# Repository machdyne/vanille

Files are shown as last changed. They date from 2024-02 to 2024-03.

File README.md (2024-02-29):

# Vanille Computer

Vanille is an FPGA computer designed by Lone Dynamics Corporation.

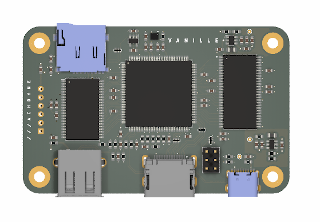
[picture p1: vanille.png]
Vanille Computer


This repo will contain schematics, PCB layouts, pinouts, a 3D-printable case, example gateware and documentation.

Find more information on the [Vanille product page](https://machdyne.com/product/vanille-computer/).

## Programming Vanille

Vanille has a JTAG interface and ships with a [DFU bootloader](https://github.com/machdyne/tinydfu-bootloader) that allows the included flash [MMOD](https://machdyne.com/product/mmod) to be programmed over the USB-C port.

### DFU

The DFU bootloader is available for 5 seconds after power-on, issuing a DFU command during this period will stop the boot process until the DFU device is detached. If no command is received the boot process will continue and the user gateware will be loaded.

Install [dfu-util](http://dfu-util.sourceforge.net) (Debian/Ubuntu):

```
$ sudo apt install dfu-util
```

Update the user gateware on the flash MMOD:

```
$ sudo dfu-util -a 0 -D image.bit
```

Detach the DFU device and continue the boot process:

```
$ sudo dfu-util -a 0 -e
```

It is possible to update the bootloader itself using DFU but you shouldn't attempt this unless you have a JTAG programmer (or another method to program the MMOD) available, in case you need to restore the bootloader.

### JTAG

These examples assume you're using a "USB Blaster" JTAG cable, see the header pinout below. You will need to have [openFPGALoader](https://github.com/trabucayre/openFPGALoader) installed.

Program the configuration SRAM:

```
openFPGALoader -c usb-blaster image.bit
```

Program the flash MMOD:

```
openFPGALoader -f -c usb-blaster images/bootloader/tinydfu_vanille.bit
```

## Blinky 

Building the blinky example requires [Yosys](https://github.com/YosysHQ/yosys), [nextpnr-ecp5](https://github.com/YosysHQ/nextpnr) and [Project Trellis](https://github.com/YosysHQ/prjtrellis).

Assuming they are installed, you can simply type `make` to build the gateware, which will be written to output/blinky.bin. You can then use [openFPGALoader](https://github.com/trabucayre/openFPGALoader) or dfu-util to write the gateware to the device.

## Linux

See the [Kakao Linux](https://github.com/machdyne/kakao) repo for the latest instructions.

### Prebuilt Images

Prebuilt gateware capable of running Linux is available in the `images/v2` directory.

### Building Linux-capable Gateware

Please follow the setup instructions in the [linux-on-litex-vexriscv](https://github.com/litex-hub/linux-on-litex-vexriscv) repo and then:

1. Build the Linux-capable gateware:

```
$ cd linux-on-litex-vexriscv
$ ./make.py --board=vanille --dcache-size=64 --icache-size=64 --build
```

NOTE: This may fail, if so:

```
$ cd build/vanille/gateware
```

Edit `vanille.ys` and add the `-abc2` option as shown below:

```
synth_ecp5  -top vanille -abc2
```

Now run:

```
$ bash build_vanille.sh
```

2. Write the gateware to the MMOD using USB DFU:

```
$ sudo dfu-util -a 0 -D vanille.bit
```

3. Copy the device tree binary `../vanille.dtb` to a FAT-formatted MicroSD card.

## JTAG Header

The 3.3V JTAG header can be used to program the FPGA SRAM as well as the MMOD flash memory. It can also be used to provide power (5V) to the board.

```
1 2
3 4
5 6
```

| Pin | Signal |
| --- | --- |
| 1 | TCK |
| 2 | TDI |
| 3 | TDO |
| 4 | TMS |
| 5 | 5V0 |
| 6 | GND |

## Board Revisions

| Revision | Notes |
| --- | ----- |
| V0 | Initial prototype |
| V1 | Second prototype; fixes SRAM schematic error; adds LED |
| V2 | Initial production version; fixes another SRAM schematic error |

## License

The contents of this repo are released under the [Lone Dynamics Open License](LICENSE.md) with the following exceptions:

- The KiCad design files contain parts of the [kicad-pmod](https://github.com/mithro/kicad-pmod) library which is released under the [Apache License, Version 2.0](https://www.apache.org/licenses/LICENSE-2.0.html).

- The KiCad design files may contain symbols and footprints released under other licenses; please contact us if we've failed to give proper attribution.

Note: You can use these designs for commercial purposes but we ask that instead of producing exact clones, that you either replace our trademarks and logos with your own or add your own next to ours.

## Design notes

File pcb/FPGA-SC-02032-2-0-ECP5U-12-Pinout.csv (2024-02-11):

# Pin Out For ECP5U-12
# Revision 1.1 - Include CABGA256 package
# Revised Oct. 17, 2017
# Revision 2.0 - Include TQFP144 package
# Revised Sep. 17, 2021
PAD | Pin/Ball Function | Bank | Dual Function | Differential | High Speed | DQS | CABGA381 | CSFBGA285 | CABGA256 | TQFP144
1 | PL2A | 7 | - | True_OF_PL2B | TRUE | LDQ8 | A4 | C12 | B1 | -
2 | PL2B | 7 | - | Comp_OF_PL2A | TRUE | LDQ8 | A5 | B12 | B2 | -
3 | VSSIO7 | - | - | - | - | - | - | - | - | -
4 | PL2C | 7 | - | True_OF_PL2D | - | LDQ8 | B5 | - | C3 | -
5 | VCCIO7 | - | - | - | - | - | - | - | - | -
6 | PL2D | 7 | - | Comp_OF_PL2C | - | LDQ8 | C5 | - | D3 | -
7 | PL5A | 7 | - | True_OF_PL5B | TRUE | LDQ8 | C4 | A12 | C1 | -
8 | VCCAUX | - | - | - | - | - | - | - | - | -
9 | PL5C | 7 | - | True_OF_PL5D | - | LDQ8 | A3 | - | E3 | 1
10 | PL5B | 7 | - | Comp_OF_PL5A | TRUE | LDQ8 | B4 | - | C2 | 3
11 | VSS | - | - | - | - | - | - | - | - | -
12 | PL5D | 7 | - | Comp_OF_PL5C | - | LDQ8 | B3 | - | F3 | 2
13 | PL8A | 7 | - | True_OF_PL8B | TRUE | LDQS8 | E4 | D13 | D1 | 4
14 | VCC | - | - | - | - | - | - | - | - | -
15 | PL8C | 7 | - | True_OF_PL8D | - | LDQ8 | C3 | - | F4 | 5
16 | PL8B | 7 | - | Comp_OF_PL8A | TRUE | LDQSN8 | D5 | C13 | E2 | 6
17 | VSS | - | - | - | - | - | - | - | - | -
18 | PL8D | 7 | - | Comp_OF_PL8C | - | LDQ8 | D3 | - | F5 | 7
19 | PL11A | 7 | - | True_OF_PL11B | TRUE | LDQ8 | F4 | - | G5 | -
20 | VSSIO7 | - | - | - | - | - | - | - | - | -
21 | PL11C | 7 | - | True_OF_PL11D | - | LDQ8 | E5 | - | F2 | -
22 | PL11B | 7 | - | Comp_OF_PL11A | TRUE | LDQ8 | E3 | - | G4 | -
23 | VCCIO7 | - | - | - | - | - | - | - | - | 9
24 | PL11D | 7 | - | Comp_OF_PL11C | - | LDQ8 | F5 | - | E1 | -
25 | PL14A | 7 | - | True_OF_PL14B | TRUE | LDQ20 | A2 | B13 | F1 | 10
26 | VSSIO7 | - | - | - | - | - | - | - | - | -
27 | PL14C | 7 | VREF1_7 | True_OF_PL14D | - | LDQ20 | B2 | C15 | G3 | 11
28 | PL14B | 7 | - | Comp_OF_PL14A | TRUE | LDQ20 | B1 | A13 | G2 | 12
29 | VCCIO7 | - | - | - | - | - | - | - | - | -
30 | PL14D | 7 | - | Comp_OF_PL14C | - | LDQ20 | C2 | A15 | H3 | 13
31 | PL17A | 7 | - | True_OF_PL17B | TRUE | LDQ20 | C1 | D15 | H5 | -
32 | VCCAUX | - | - | - | - | - | - | - | - | -
33 | PL17C | 7 | - | True_OF_PL17D | - | LDQ20 | D2 | - | J4 | -
34 | PL17B | 7 | - | Comp_OF_PL17A | TRUE | LDQ20 | D1 | D16 | H4 | -
35 | VSS | - | - | - | - | - | - | - | - | -
36 | PL17D | 7 | - | Comp_OF_PL17C | - | LDQ20 | E1 | - | J5 | -
37 | PL20A | 7 | GR_PCLK7_1 | True_OF_PL20B | TRUE | LDQS20 | H4 | B15 | G1 | -
38 | VCC | - | - | - | - | - | - | - | - | -
39 | PL20C | 7 | GR_PCLK7_0 | True_OF_PL20D | - | LDQ20 | H5 | C16 | J3 | -
40 | PL20B | 7 | - | Comp_OF_PL20A | TRUE | LDQSN20 | G5 | A16 | H2 | -
41 | VSS | - | - | - | - | - | - | - | - | -
42 | PL20D | 7 | - | Comp_OF_PL20C | - | LDQ20 | H3 | - | K3 | -
43 | PL23A | 7 | PCLKT7_1 | True_OF_PL23B | TRUE | LDQ20 | G3 | A17 | J1 | -
44 | VSSIO7 | - | - | - | - | - | - | - | - | -
45 | PL23C | 7 | PCLKT7_0 | True_OF_PL23D | - | LDQ20 | F2 | B18 | K1 | -
46 | PL23B | 7 | PCLKC7_1 | Comp_OF_PL23A | TRUE | LDQ20 | F3 | B17 | J2 | -
47 | VCCIO7 | - | - | - | - | - | - | - | - | -
48 | PL23D | 7 | PCLKC7_0 | Comp_OF_PL23C | - | LDQ20 | E2 | C17 | K2 | 14
49 | PL26A | 6 | PCLKT6_1 | True_OF_PL26B | TRUE | LDQ32 | G2 | D17 | L1 | -
50 | VSSIO6 | - | - | - | - | - | - | - | - | -
51 | PL26C | 6 | PCLKT6_0 | True_OF_PL26D | - | LDQ32 | H2 | D18 | M1 | -
52 | PL26B | 6 | PCLKC6_1 | Comp_OF_PL26A | TRUE | LDQ32 | F1 | C18 | L2 | -
53 | VCCIO6 | - | - | - | - | - | - | - | - | -
54 | PL26D | 6 | PCLKC6_0 | Comp_OF_PL26C | - | LDQ32 | G1 | F18 | M2 | -
55 | PL29A | 6 | GR_PCLK6_0 | True_OF_PL29B | TRUE | LDQ32 | J4 | F17 | K4 | -
56 | VCCAUX | - | - | - | - | - | - | - | - | -
57 | PL29C | 6 | GR_PCLK6_1 | True_OF_PL29D | - | LDQ32 | J3 | F15 | L4 | -
58 | PL29B | 6 | - | Comp_OF_PL29A | TRUE | LDQ32 | J5 | F16 | K5 | -
59 | VSS | - | - | - | - | - | - | - | - | -
60 | PL29D | 6 | - | Comp_OF_PL29C | - | LDQ32 | K3 | G16 | L5 | -
61 | PL32A | 6 | - | True_OF_PL32B | TRUE | LDQS32 | K2 | G18 | N1 | -
62 | VCC | - | - | - | - | - | - | - | - | -
63 | PL32C | 6 | - | True_OF_PL32D | - | LDQ32 | H1 | - | L3 | -
64 | PL32B | 6 | - | Comp_OF_PL32A | TRUE | LDQSN32 | J1 | H17 | P2 | 18
65 | VSS | - | - | - | - | - | - | - | - | -
66 | PL32D | 6 | - | Comp_OF_PL32C | - | LDQ32 | K1 | - | M3 | -
67 | PL35A | 6 | - | True_OF_PL35B | TRUE | LDQ32 | K4 | G15 | P1 | -
68 | VSSIO6 | - | - | - | - | - | - | - | - | -
69 | PL35C | 6 | - | True_OF_PL35D | - | LDQ32 | L4 | H16 | M4 | 22
70 | PL35B | 6 | VREF1_6 | Comp_OF_PL35A | TRUE | LDQ32 | K5 | H15 | R1 | 19
71 | VCCIO6 | - | - | - | - | - | - | - | - | -
72 | PL35D | 6 | - | Comp_OF_PL35C | - | LDQ32 | L5 | J16 | N3 | 23
73 | PL38A | 6 | - | True_OF_PL38B | TRUE | LDQ44 | M4 | - | N4 | 24
74 | VSSIO6 | - | - | - | - | - | - | - | - | -
75 | PL38C | 6 | - | True_OF_PL38D | - | LDQ44 | N4 | J17 | R2 | -
76 | PL38B | 6 | - | Comp_OF_PL38A | TRUE | LDQ44 | N5 | - | P3 | 25
77 | VCCIO6 | - | - | - | - | - | - | - | - | -
78 | PL38D | 6 | - | Comp_OF_PL38C | - | LDQ44 | P5 | H18 | T2 | -
79 | PL41A | 6 | - | True_OF_PL41B | TRUE | LDQ44 | N3 | J18 | P4 | -
80 | VCCAUX | - | - | - | - | - | - | - | - | -
81 | PL41C | 6 | - | True_OF_PL41D | - | LDQ44 | L3 | K16 | R4 | 26
82 | PL41B | 6 | - | Comp_OF_PL41A | TRUE | LDQ44 | M3 | K18 | R3 | -
83 | VSS | - | - | - | - | - | - | - | - | -
84 | PL41D | 6 | - | Comp_OF_PL41C | - | LDQ44 | L2 | K15 | T3 | 27
85 | PL44A | 6 | - | True_OF_PL44B | TRUE | LDQS44 | N2 | K17 | R5 | 28
86 | VCC | - | - | - | - | - | - | - | - | -
87 | PL44C | 6 | - | True_OF_PL44D | - | LDQ44 | L1 | L15 | M5 | 31
88 | PL44B | 6 | - | Comp_OF_PL44A | TRUE | LDQSN44 | M1 | L18 | T4 | 30
89 | VSS | - | - | - | - | - | - | - | - | -
90 | PL44D | 6 | - | Comp_OF_PL44C | - | LDQ44 | N1 | L16 | N5 | 33
91 | PL47A | 6 | - | True_OF_PL47B | TRUE | LDQ44 | P1 | - | M6 | 34
92 | VSSIO6 | - | - | - | - | - | - | - | - | 32
93 | PL47B | 6 | - | Comp_OF_PL47A | TRUE | LDQ44 | P2 | - | N6 | 35
94 | VCCIO6 | - | - | - | - | - | - | - | - | -
95 | PL47C | 6 | LLC_GPLL0T_IN | True_OF_PL47D | - | LDQ44 | P3 | M16 | P6 | 37
96 | PL47D | 6 | LLC_GPLL0C_IN | Comp_OF_PL47C | - | LDQ44 | P4 | M17 | P5 | -
97 | NC | - | - | - | - | - | - | - | - | -
98 | NC | - | - | - | - | - | - | - | - | -
99 | GND | - | - | - | - | - | - | - | - | -
100 | VCC | - | - | - | - | - | - | - | - | -
101 | VCC | - | - | - | - | - | - | - | - | -
102 | VSS | - | - | - | - | - | - | - | - | -
103 | PB4A | 8 | D7/IO7 | True_OF_PB4B | - | - | R1 | N15 | T6 | 40
104 | PB6A | 8 | D5/MISO2/IO5 | True_OF_PB6B | - | - | U1 | N17 | R7 | 39
105 | VCC | - | - | - | - | - | - | - | - | -
106 | PB4B | 8 | D6/IO6 | Comp_OF_PB4A | - | - | T1 | N16 | R6 | 44
107 | PB6B | 8 | D4/MOSI2/IO4 | Comp_OF_PB6A | - | - | V1 | M18 | P7 | 41
108 | VSS | - | - | - | - | - | - | - | - | -
109 | PB9A | 8 | D3/IO3 | True_OF_PB9B | - | - | W1 | N18 | N7 | 45
110 | PB11A | 8 | D1/MISO/IO1 | True_OF_PB11B | - | - | V2 | T18 | T7 | 46
111 | VSSIO8 | - | - | - | - | - | - | - | - | -
112 | PB9B | 8 | D2/IO2 | Comp_OF_PB9A | - | - | Y2 | R18 | M7 | -
113 | PB11B | 8 | D0/MOSI/IO0 | Comp_OF_PB11A | - | - | W2 | U18 | T8 | 47
114 | VCCIO8 | - | - | - | - | - | - | - | - | 43
115 | PB13A | 8 | SN/CSN | True_OF_PB13B | - | - | T2 | R17 | R8 | 48
116 | PB15A | 8 | HOLDN/DI/BUSY/CSSPIN/CEN | True_OF_PB15B | - | - | R2 | U17 | N8 | 49
117 | VSSIO8 | - | - | - | - | - | - | - | - | -
118 | PB13B | 8 | CS1N | Comp_OF_PB13A | - | - | U2 | T17 | P8 | 50
119 | PB15B | 8 | DOUT/CSON | Comp_OF_PB15A | - | - | R3 | V17 | M8 | 51
120 | VCCIO8 | - | - | - | - | - | - | - | - | -
121 | PB18A | 8 | WRITEN | - | - | - | T3 | R16 | M9 | 52
122 | INITN | 8 | - | - | - | - | V3 | V16 | T9 | 55
123 | VCCAUX | - | - | - | - | - | - | - | - | -
124 | CCLK | 8 | MCLK/SCK | - | - | - | U3 | U16 | N9 | 54
125 | PROGRAMN | 8 | - | - | - | - | W3 | T15 | R9 | 57
126 | VSS | - | - | - | - | - | - | - | - | -
127 | DONE | 8 | - | - | - | - | Y3 | U15 | P9 | 56
128 | CFG_1 | 8 | - | - | - | - | T4 | T14 | P10 | 59
129 | VCC | - | - | - | - | - | - | - | - | -
130 | CFG_2 | 8 | - | - | - | - | R4 | V15 | R10 | 58
131 | CFG_0 | 8 | - | - | - | - | U4 | U14 | N10 | 62
132 | VSS | - | - | - | - | - | - | - | - | -
133 | TDO | 40 | - | - | - | - | V4 | V14 | M10 | 60
134 | TCK | 40 | - | - | - | - | T5 | U13 | T10 | 63
135 | VSSIO8 | - | - | - | - | - | - | - | - | -
136 | TDI | 40 | - | - | - | - | R5 | T13 | R11 | 61
137 | TMS | 40 | - | - | - | - | U5 | V13 | T11 | 64
138 | VCCIO8 | - | - | - | - | - | - | - | - | -
139 | VCC | - | - | - | - | - | - | - | - | -
140 | VCC | - | - | - | - | - | - | - | - | -
141 | VSS | - | - | - | - | - | - | - | - | -
142 | VSS | - | - | - | - | - | - | - | - | -
143 | VCC | - | - | - | - | - | - | - | - | -
144 | VCC | - | - | - | - | - | - | - | - | -
145 | GND | - | - | - | - | - | - | - | - | -
146 | GND | - | - | - | - | - | - | - | - | -
147 | RESERVED | - | - | - | - | - | W4 | V12 | - | -
148 | GND | - | - | - | - | - | T7 | U12 | - | -
149 | RESERVED | - | - | - | - | - | W5 | V11 | - | -
150 | GND | - | - | - | - | - | - | - | - | -
151 | GND | - | - | - | - | - | - | - | - | -
152 | GND | - | - | - | - | - | Y5 | V9 | - | -
153 | GND | - | - | - | - | - | - | - | - | -
154 | GND | - | - | - | - | - | T8 | U8 | - | -
155 | GND | - | - | - | - | - | Y6 | V8 | - | -
156 | GND | - | - | - | - | - | - | - | - | -
157 | GND | - | - | - | - | - | - | - | - | -
158 | GND | - | - | - | - | - | Y7 | V6 | - | -
159 | GND | - | - | - | - | - | - | - | - | -
160 | GND | - | - | - | - | - | T9 | U6 | - | -
161 | GND | - | - | - | - | - | Y8 | V5 | - | -
162 | GND | - | - | - | - | - | - | - | - | -
163 | GND | - | - | - | - | - | - | - | - | -
164 | RESERVED | - | - | - | - | - | W8 | V3 | - | -
165 | GND | - | - | - | - | - | T10 | T5 | - | -
166 | RESERVED | - | - | - | - | - | W9 | V2 | - | -
167 | GND | - | - | - | - | - | - | - | - | -
168 | GND | - | - | - | - | - | - | - | - | -
169 | RESERVED | - | - | - | - | - | W10 | - | - | -
170 | GND | - | - | - | - | - | - | - | - | -
171 | RESERVED | - | - | - | - | - | W11 | - | - | -
172 | GND | - | - | - | - | - | - | - | - | -
173 | GND | - | - | - | - | - | - | - | - | -
174 | GND | - | - | - | - | - | Y11 | U1 | - | -
175 | GND | - | - | - | - | - | - | - | - | -
176 | GND | - | - | - | - | - | Y12 | T1 | - | -
177 | VCC | - | - | - | - | - | - | - | - | -
178 | VSS | - | - | - | - | - | - | - | - | -
179 | VCC | - | - | - | - | - | - | - | - | -
180 | GND | - | - | - | - | - | - | - | - | -
181 | NC | - | - | - | - | - | - | - | - | -
182 | NC | - | - | - | - | - | - | - | - | -
183 | PR47D | 3 | LRC_GPLL0C_IN | Comp_OF_PR47C | - | RDQ44 | T17 | N1 | P12 | 68
184 | PR47C | 3 | LRC_GPLL0T_IN | True_OF_PR47D | - | RDQ44 | U16 | M1 | P11 | 69
185 | VCCIO3 | - | - | - | - | - | - | - | - | -
186 | PR47B | 3 | - | Comp_OF_PR47A | TRUE | RDQ44 | U17 | - | N11 | 67
187 | VSSIO3 | - | - | - | - | - | - | - | - | -
188 | PR47A | 3 | - | True_OF_PR47B | TRUE | RDQ44 | U18 | - | M11 | 71
189 | PR44D | 3 | - | Comp_OF_PR44C | - | RDQ44 | T18 | N2 | N12 | -
190 | VSS | - | - | - | - | - | - | - | - | -
191 | PR44B | 3 | - | Comp_OF_PR44A | TRUE | RDQSN44 | R18 | L1 | T13 | -
192 | PR44C | 3 | - | True_OF_PR44D | - | RDQ44 | U19 | M2 | M12 | 72
193 | VCC | - | - | - | - | - | - | - | - | -
194 | PR44A | 3 | - | True_OF_PR44B | TRUE | RDQS44 | T19 | K2 | R12 | -
195 | PR41D | 3 | - | Comp_OF_PR41C | - | RDQ44 | U20 | K1 | T14 | 73
196 | VSS | - | - | - | - | - | - | - | - | -
197 | PR41B | 3 | - | Comp_OF_PR41A | TRUE | RDQ44 | R20 | L3 | R14 | 76
198 | PR41C | 3 | - | True_OF_PR41D | - | RDQ44 | T20 | K3 | R13 | 74
199 | VCCAUX | - | - | - | - | - | - | - | - | -
200 | PR41A | 3 | - | True_OF_PR41B | TRUE | RDQ44 | P20 | M3 | P13 | 77
201 | PR38D | 3 | - | Comp_OF_PR38C | - | RDQ44 | P18 | N3 | T15 | -
202 | VCCIO3 | - | - | - | - | - | - | - | - | -
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

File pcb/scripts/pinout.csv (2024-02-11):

LFE5U-12-TG144
Pin | Unit | Type | Name
1 | 7 | bidirectional | PL5C/+/LDQ8
3 | 7 | bidirectional | PL5B/-/HS/LDQ8
2 | 7 | bidirectional | PL5D/-/LDQ8
4 | 7 | bidirectional | PL8A/+/HS/LDQS8
5 | 7 | bidirectional | PL8C/+/LDQ8
6 | 7 | bidirectional | PL8B/-/HS/LDQSN8
7 | 7 | bidirectional | PL8D/-/LDQ8
9 | 7 | power_in | VCCIO7
10 | 7 | bidirectional | PL14A/+/HS/LDQ20
11 | 7 | bidirectional | PL14C/+/LDQ20/VREF1_7
12 | 7 | bidirectional | PL14B/-/HS/LDQ20
13 | 7 | bidirectional | PL14D/-/LDQ20
14 | 7 | bidirectional | PL23D/-/LDQ20/PCLKC7_0
18 | 6 | bidirectional | PL32B/-/HS/LDQSN32
22 | 6 | bidirectional | PL35C/+/LDQ32
19 | 6 | bidirectional | PL35B/-/HS/LDQ32/VREF1_6
23 | 6 | bidirectional | PL35D/-/LDQ32
24 | 6 | bidirectional | PL38A/+/HS/LDQ44
25 | 6 | bidirectional | PL38B/-/HS/LDQ44
26 | 6 | bidirectional | PL41C/+/LDQ44
27 | 6 | bidirectional | PL41D/-/LDQ44
28 | 6 | bidirectional | PL44A/+/HS/LDQS44
31 | 6 | bidirectional | PL44C/+/LDQ44
30 | 6 | bidirectional | PL44B/-/HS/LDQSN44
33 | 6 | bidirectional | PL44D/-/LDQ44
34 | 6 | bidirectional | PL47A/+/HS/LDQ44
32 | 6 | power_out | VSSIO6
35 | 6 | bidirectional | PL47B/-/HS/LDQ44
37 | 6 | bidirectional | PL47C/+/LDQ44/LLC_GPLL0T_IN
40 | 8 | bidirectional | PB4A/+/D7/IO7
39 | 8 | bidirectional | PB6A/+/D5/MISO2/IO5
44 | 8 | bidirectional | PB4B/-/D6/IO6
41 | 8 | bidirectional | PB6B/-/D4/MOSI2/IO4
45 | 8 | bidirectional | PB9A/+/D3/IO3
46 | 8 | bidirectional | PB11A/+/D1/MISO/IO1
47 | 8 | bidirectional | PB11B/-/D0/MOSI/IO0
43 | 8 | power_in | VCCIO8
48 | 8 | bidirectional | PB13A/+/SN/CSN
49 | 8 | bidirectional | PB15A/+/HOLDN/DI/BUSY/CSSPIN/CEN
50 | 8 | bidirectional | PB13B/-/CS1N
51 | 8 | bidirectional | PB15B/-/DOUT/CSON
52 | 8 | bidirectional | PB18A/WRITEN
55 | 8 | bidirectional | INITN
54 | 8 | bidirectional | CCLK/MCLK/SCK
57 | 8 | bidirectional | PROGRAMN
56 | 8 | bidirectional | DONE
59 | 8 | bidirectional | CFG_1
58 | 8 | bidirectional | CFG_2
62 | 8 | bidirectional | CFG_0
60 | 40 | bidirectional | TDO
63 | 40 | bidirectional | TCK
61 | 40 | bidirectional | TDI
64 | 40 | bidirectional | TMS
68 | 3 | bidirectional | PR47D/-/RDQ44/LRC_GPLL0C_IN
69 | 3 | bidirectional | PR47C/+/RDQ44/LRC_GPLL0T_IN
67 | 3 | bidirectional | PR47B/-/HS/RDQ44
71 | 3 | bidirectional | PR47A/+/HS/RDQ44
72 | 3 | bidirectional | PR44C/+/RDQ44
73 | 3 | bidirectional | PR41D/-/RDQ44
76 | 3 | bidirectional | PR41B/-/HS/RDQ44
74 | 3 | bidirectional | PR41C/+/RDQ44
77 | 3 | bidirectional | PR41A/+/HS/RDQ44
78 | 3 | bidirectional | PR35D/-/RDQ32
79 | 3 | bidirectional | PR35B/-/HS/RDQ32/VREF1_3
80 | 3 | bidirectional | PR35C/+/RDQ32
81 | 3 | bidirectional | PR35A/+/HS/RDQ32
82 | 3 | bidirectional | PR32D/-/RDQ32
84 | 3 | bidirectional | PR32C/+/RDQ32
88 | 2 | bidirectional | PR23D/-/RDQ20/PCLKC2_0
89 | 2 | bidirectional | PR23B/-/HS/RDQ20/PCLKC2_1
90 | 2 | bidirectional | PR23C/+/RDQ20/PCLKT2_0
91 | 2 | bidirectional | PR23A/+/HS/RDQ20/PCLKT2_1
92 | 2 | bidirectional | PR20D/-/RDQ20
93 | 2 | bidirectional | PR20B/-/HS/RDQSN20
94 | 2 | bidirectional | PR20C/+/RDQ20/GR_PCLK2_0
95 | 2 | bidirectional | PR20A/+/HS/RDQS20/GR_PCLK2_1
97 | 2 | bidirectional | PR14B/-/HS/RDQ20
98 | 2 | bidirectional | PR14C/+/RDQ20/VREF1_2
99 | 2 | bidirectional | PR14A/+/HS/RDQ20
100 | 2 | power_in | VCCIO2
102 | 2 | bidirectional | PR8D/-/RDQ8
103 | 2 | bidirectional | PR8B/-/HS/RDQSN8
104 | 2 | bidirectional | PR8C/+/RDQ8
105 | 2 | bidirectional | PR8A/+/HS/RDQS8
106 | 2 | bidirectional | PR2D/-/RDQ8
107 | 2 | bidirectional | PR2C/+/RDQ8
108 | 2 | bidirectional | PR2B/-/HS/RDQ8/S0_IN
110 | 1 | bidirectional | PT67A/+
111 | 1 | bidirectional | PT62B/-
113 | 1 | bidirectional | PT60B/-
112 | 1 | bidirectional | PT62A/+
114 | 1 | bidirectional | PT60A/+
115 | 1 | bidirectional | PT58B/-
117 | 1 | bidirectional | PT56B/-
116 | 1 | bidirectional | PT58A/+
118 | 1 | bidirectional | PT56A/+
119 | 1 | bidirectional | PT53B/-
120 | 1 | bidirectional | PT53A/+
121 | 1 | bidirectional | PT51A/+
122 | 1 | power_in | VCCIO1
124 | 1 | bidirectional | PT42B/-
125 | 1 | bidirectional | PT42A/+
126 | 1 | bidirectional | PT40B/-
127 | 1 | bidirectional | PT40A/+
128 | 0 | bidirectional | PT29A/+/PCLKT0_0
133 | 0 | bidirectional | PT15B/-
135 | 0 | bidirectional | PT13B/-
134 | 0 | bidirectional | PT15A/+
136 | 0 | bidirectional | PT13A/+
137 | 0 | power_in | VCCIO0
139 | 0 | bidirectional | PT9B/-
140 | 0 | bidirectional | PT9A/+
141 | 0 | bidirectional | PT6B/-
142 | 0 | bidirectional | PT4B/-
143 | 0 | bidirectional | PT6A/+
20 | 0 | power_in | VCC
29 | 0 | power_in | VCC
66 | 0 | power_in | VCC
83 | 0 | power_in | VCC
130 | 0 | power_in | VCC
38 | 0 | power_in | VCC
17 | 0 | power_in | VCCAUX
53 | 0 | power_in | VCCAUX
96 | 0 | power_in | VCCAUX
132 | 0 | power_in | VCCAUX
70 | 3 | power_in | VCCIO3
86 | 3 | power_in | VCCIO3
16 | 6 | power_in | VCCIO6
36 | 6 | power_in | VCCIO6
8 | 6 | power_out | GND
15 | 6 | power_out | GND
21 | 6 | power_out | GND
42 | 6 | power_out | GND
65 | 6 | power_out | GND
75 | 6 | power_out | GND
85 | 6 | power_out | GND
87 | 6 | power_out | GND
101 | 6 | power_out | GND
123 | 6 | power_out | GND
129 | 6 | power_out | GND
131 | 6 | power_out | GND
138 | 6 | power_out | GND
109 | 6 | bidirectional | NC
144 | 6 | bidirectional | NC

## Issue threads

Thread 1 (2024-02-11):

FPGA Kicad model?

jeandet, 2024-02-11:
Hello, I wonder if you made this board with Kicad and if you would mind sharing the kicad symbol for the FPGA? That would be awesome. I'm planing to make an open-source board based on ECP5 TQ144 FPGAs.

machdyne, 2024-02-11:
Sure. I've added the symbol and the scripts I used to generate it to the pcb/scripts directory.

Please make sure to verify that the symbol is correct, and let me know if you find any problems.

The entire board will be open-sourced after the prototype is built and tested, hopefully later this month.

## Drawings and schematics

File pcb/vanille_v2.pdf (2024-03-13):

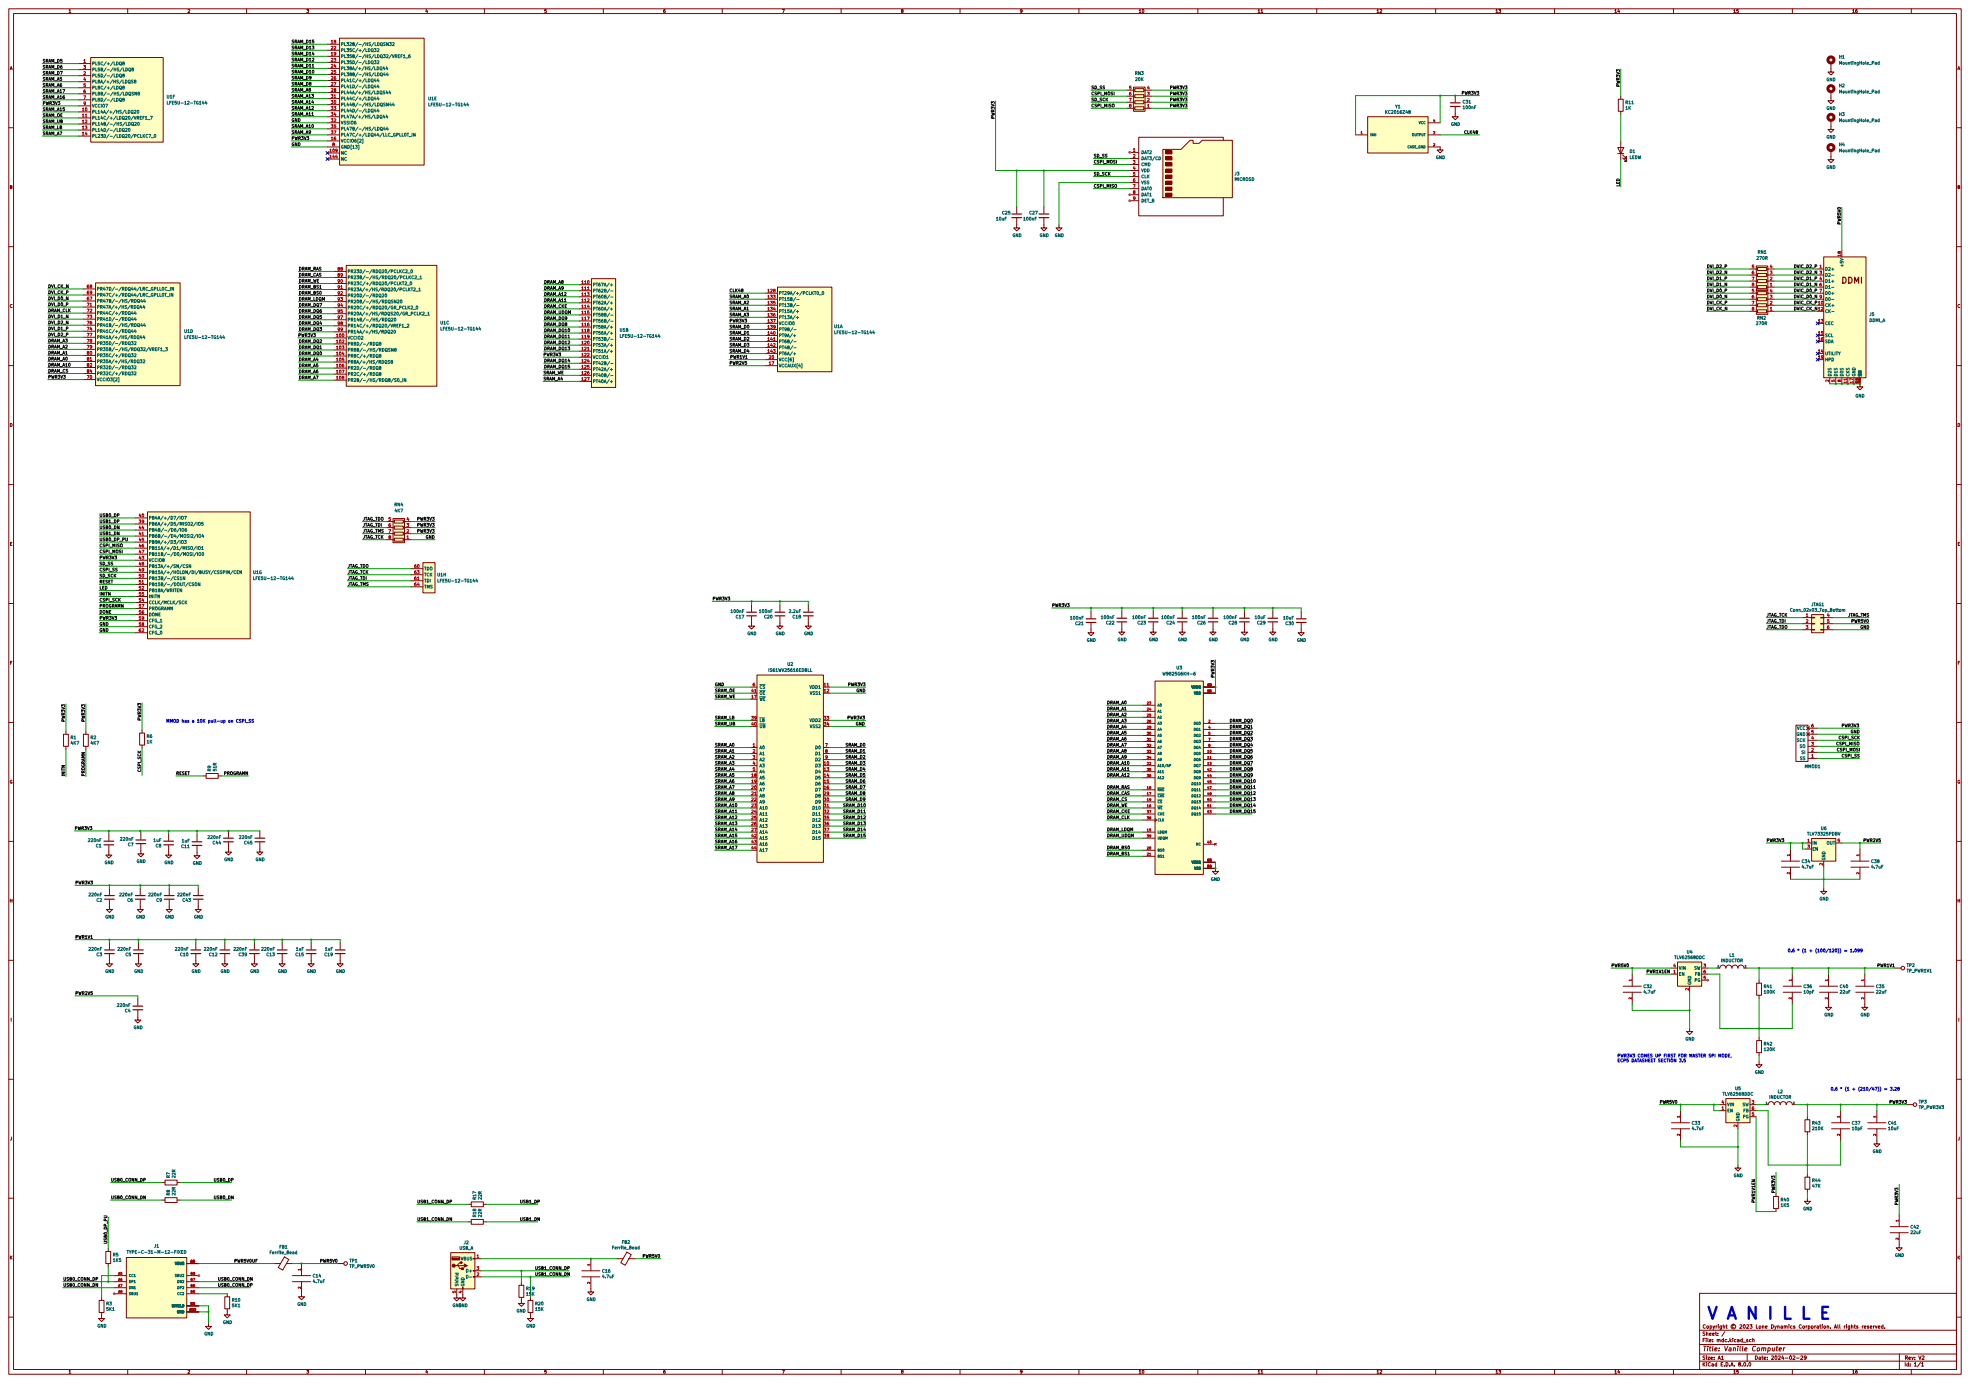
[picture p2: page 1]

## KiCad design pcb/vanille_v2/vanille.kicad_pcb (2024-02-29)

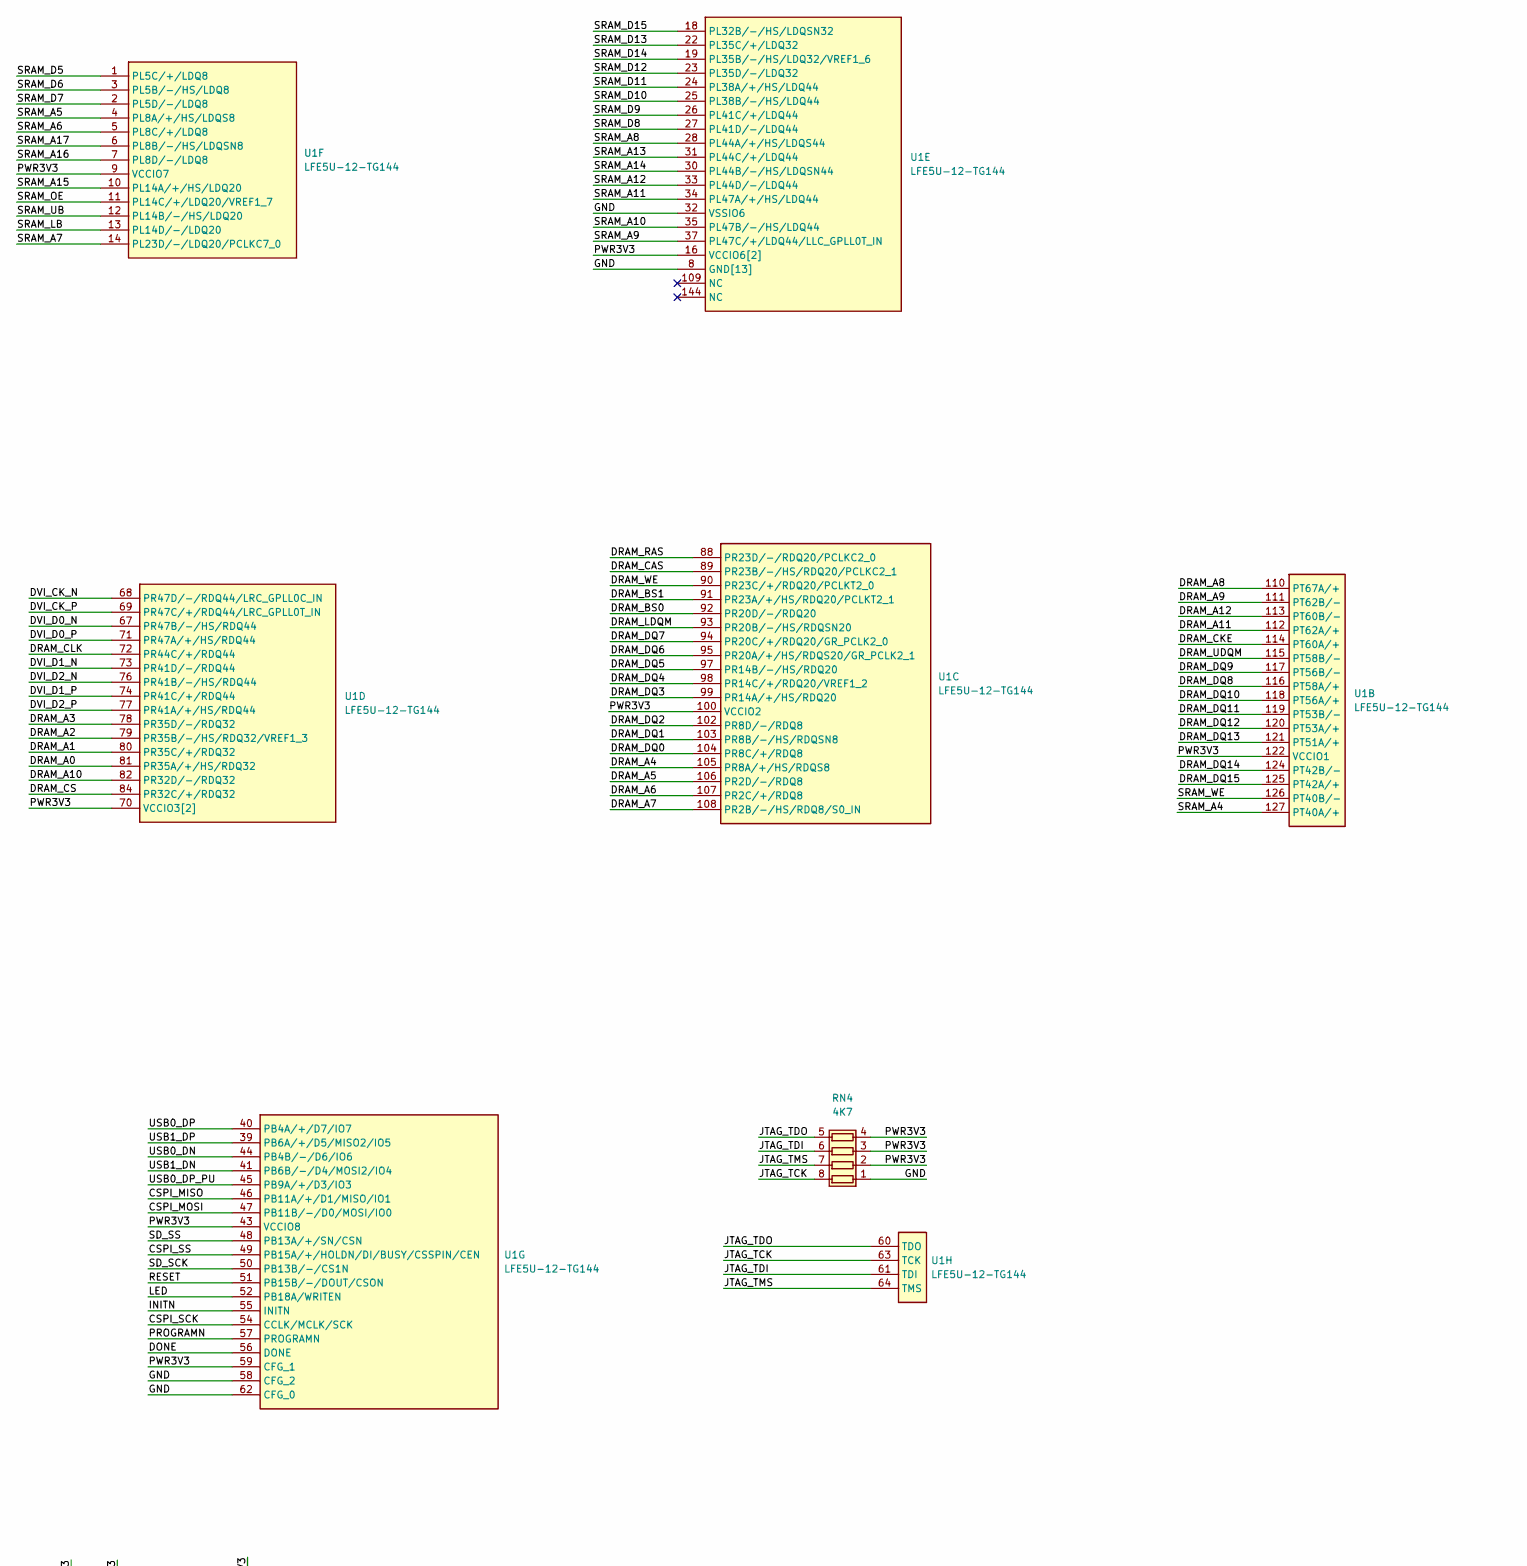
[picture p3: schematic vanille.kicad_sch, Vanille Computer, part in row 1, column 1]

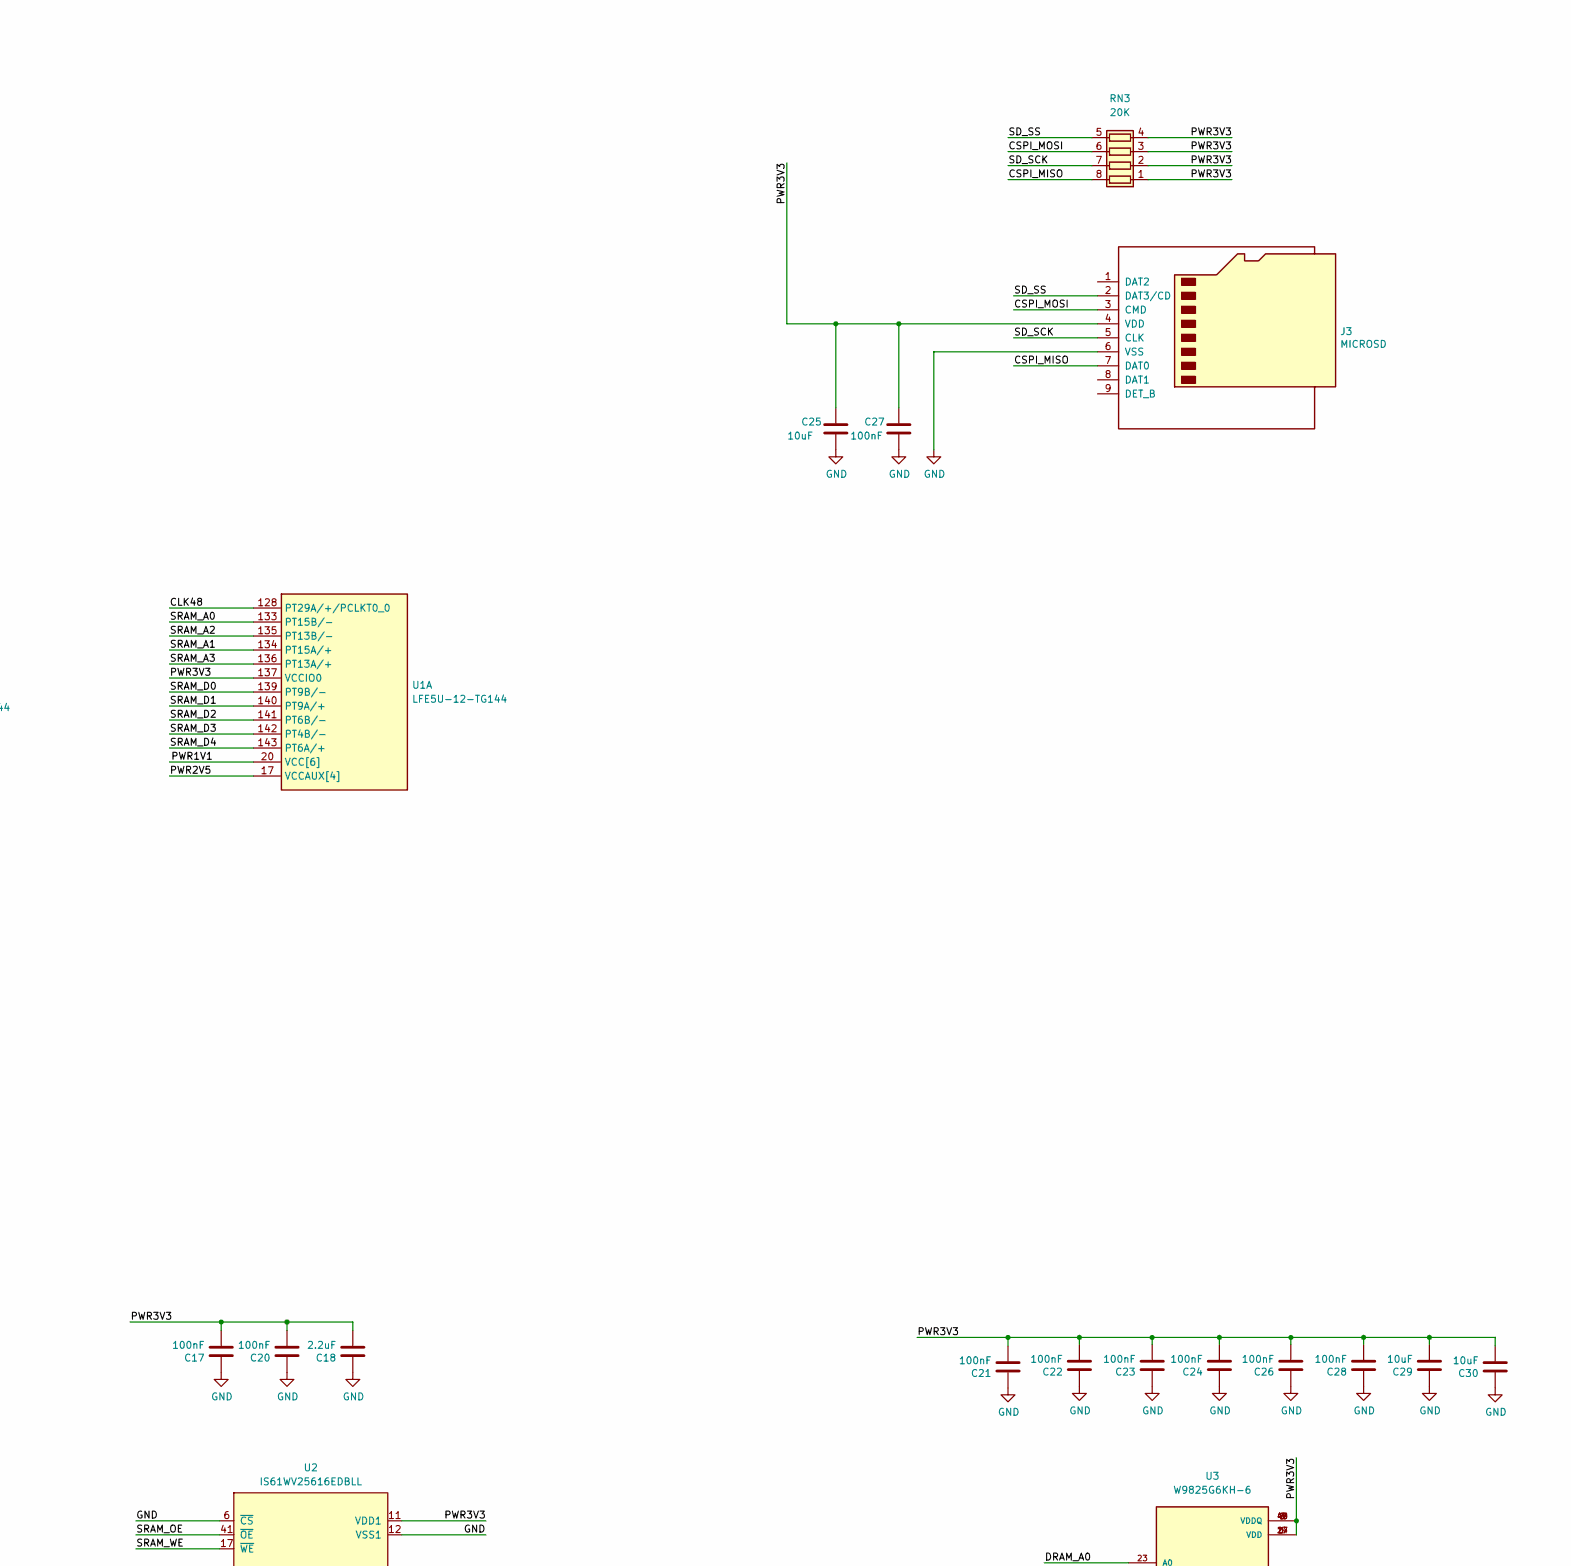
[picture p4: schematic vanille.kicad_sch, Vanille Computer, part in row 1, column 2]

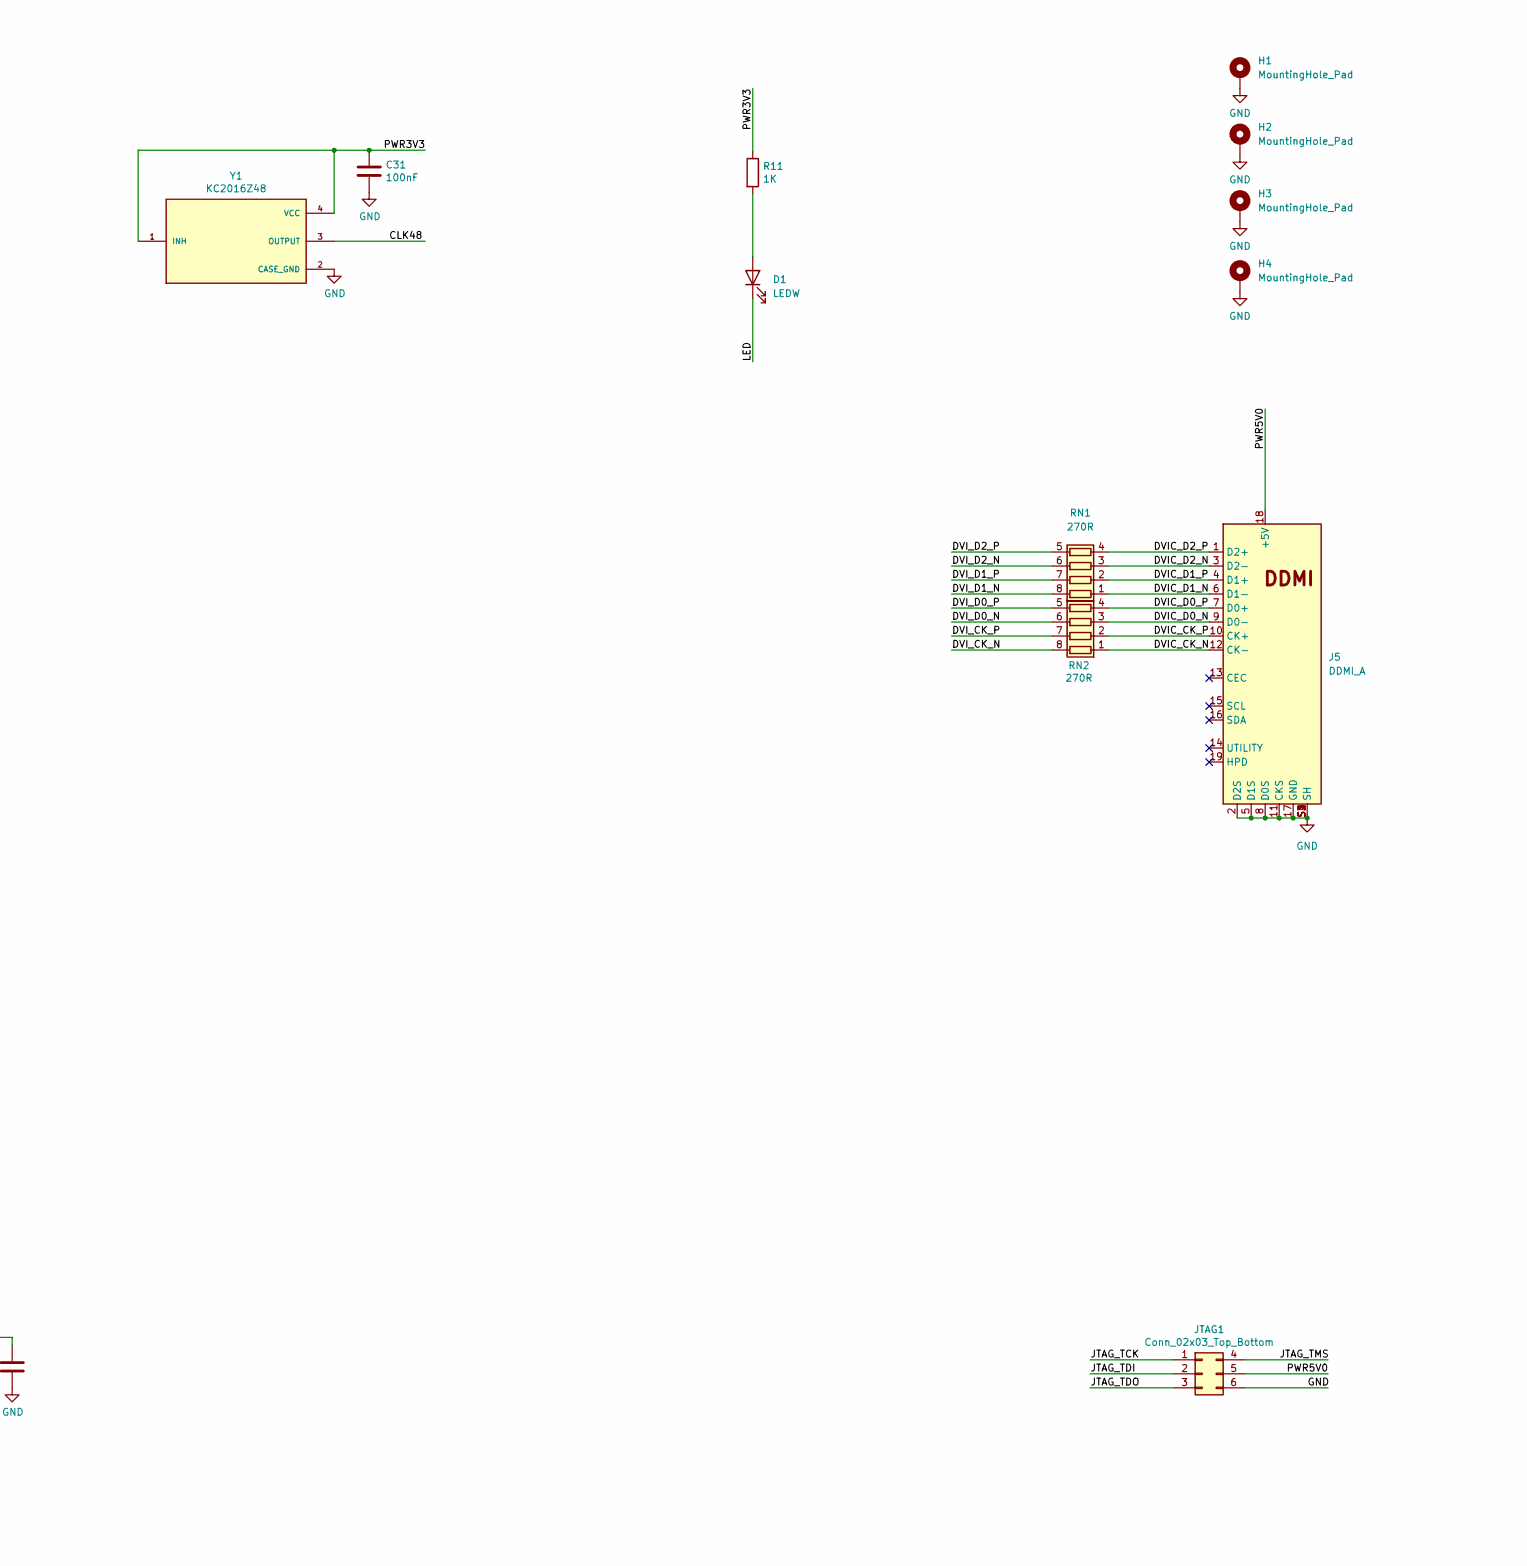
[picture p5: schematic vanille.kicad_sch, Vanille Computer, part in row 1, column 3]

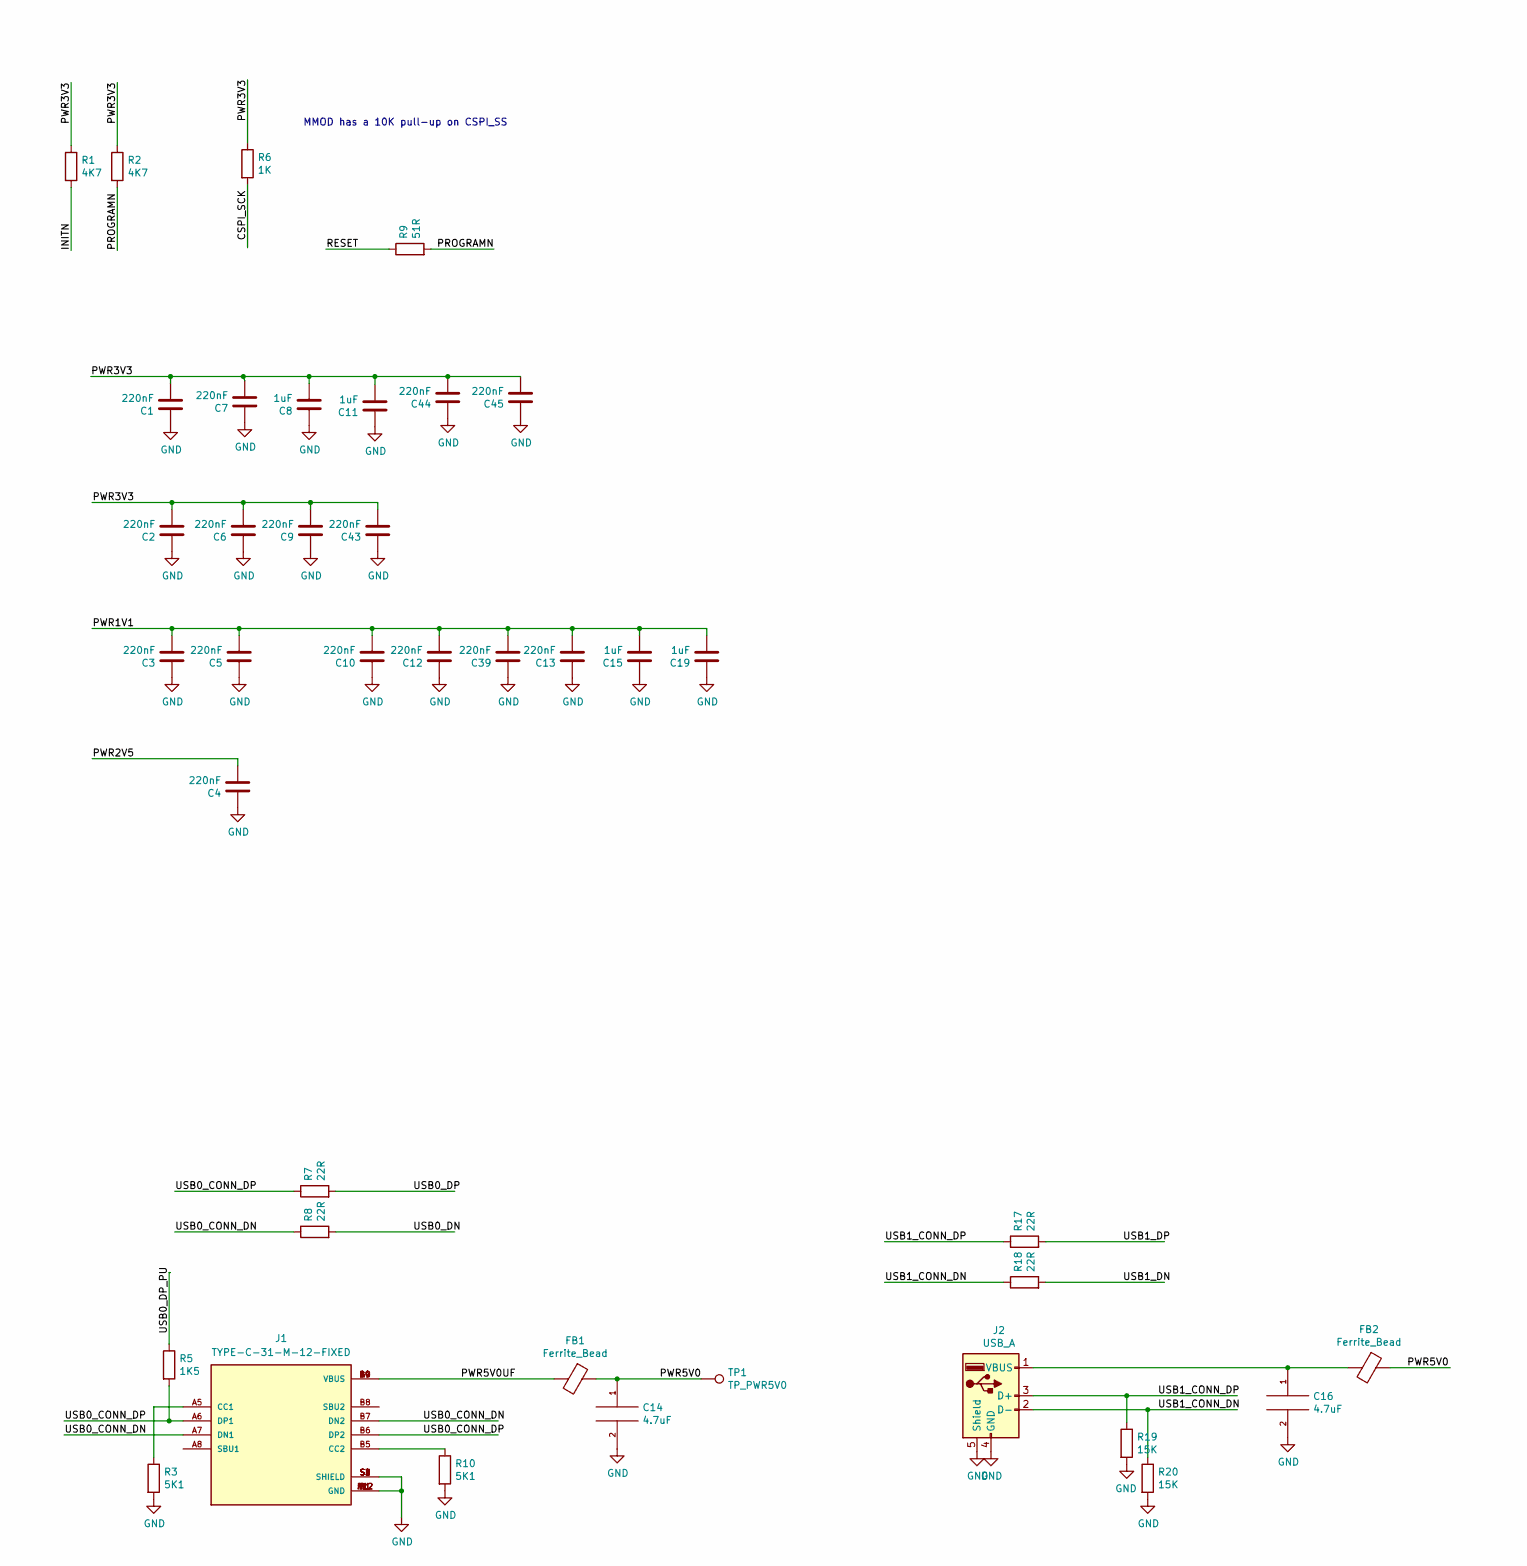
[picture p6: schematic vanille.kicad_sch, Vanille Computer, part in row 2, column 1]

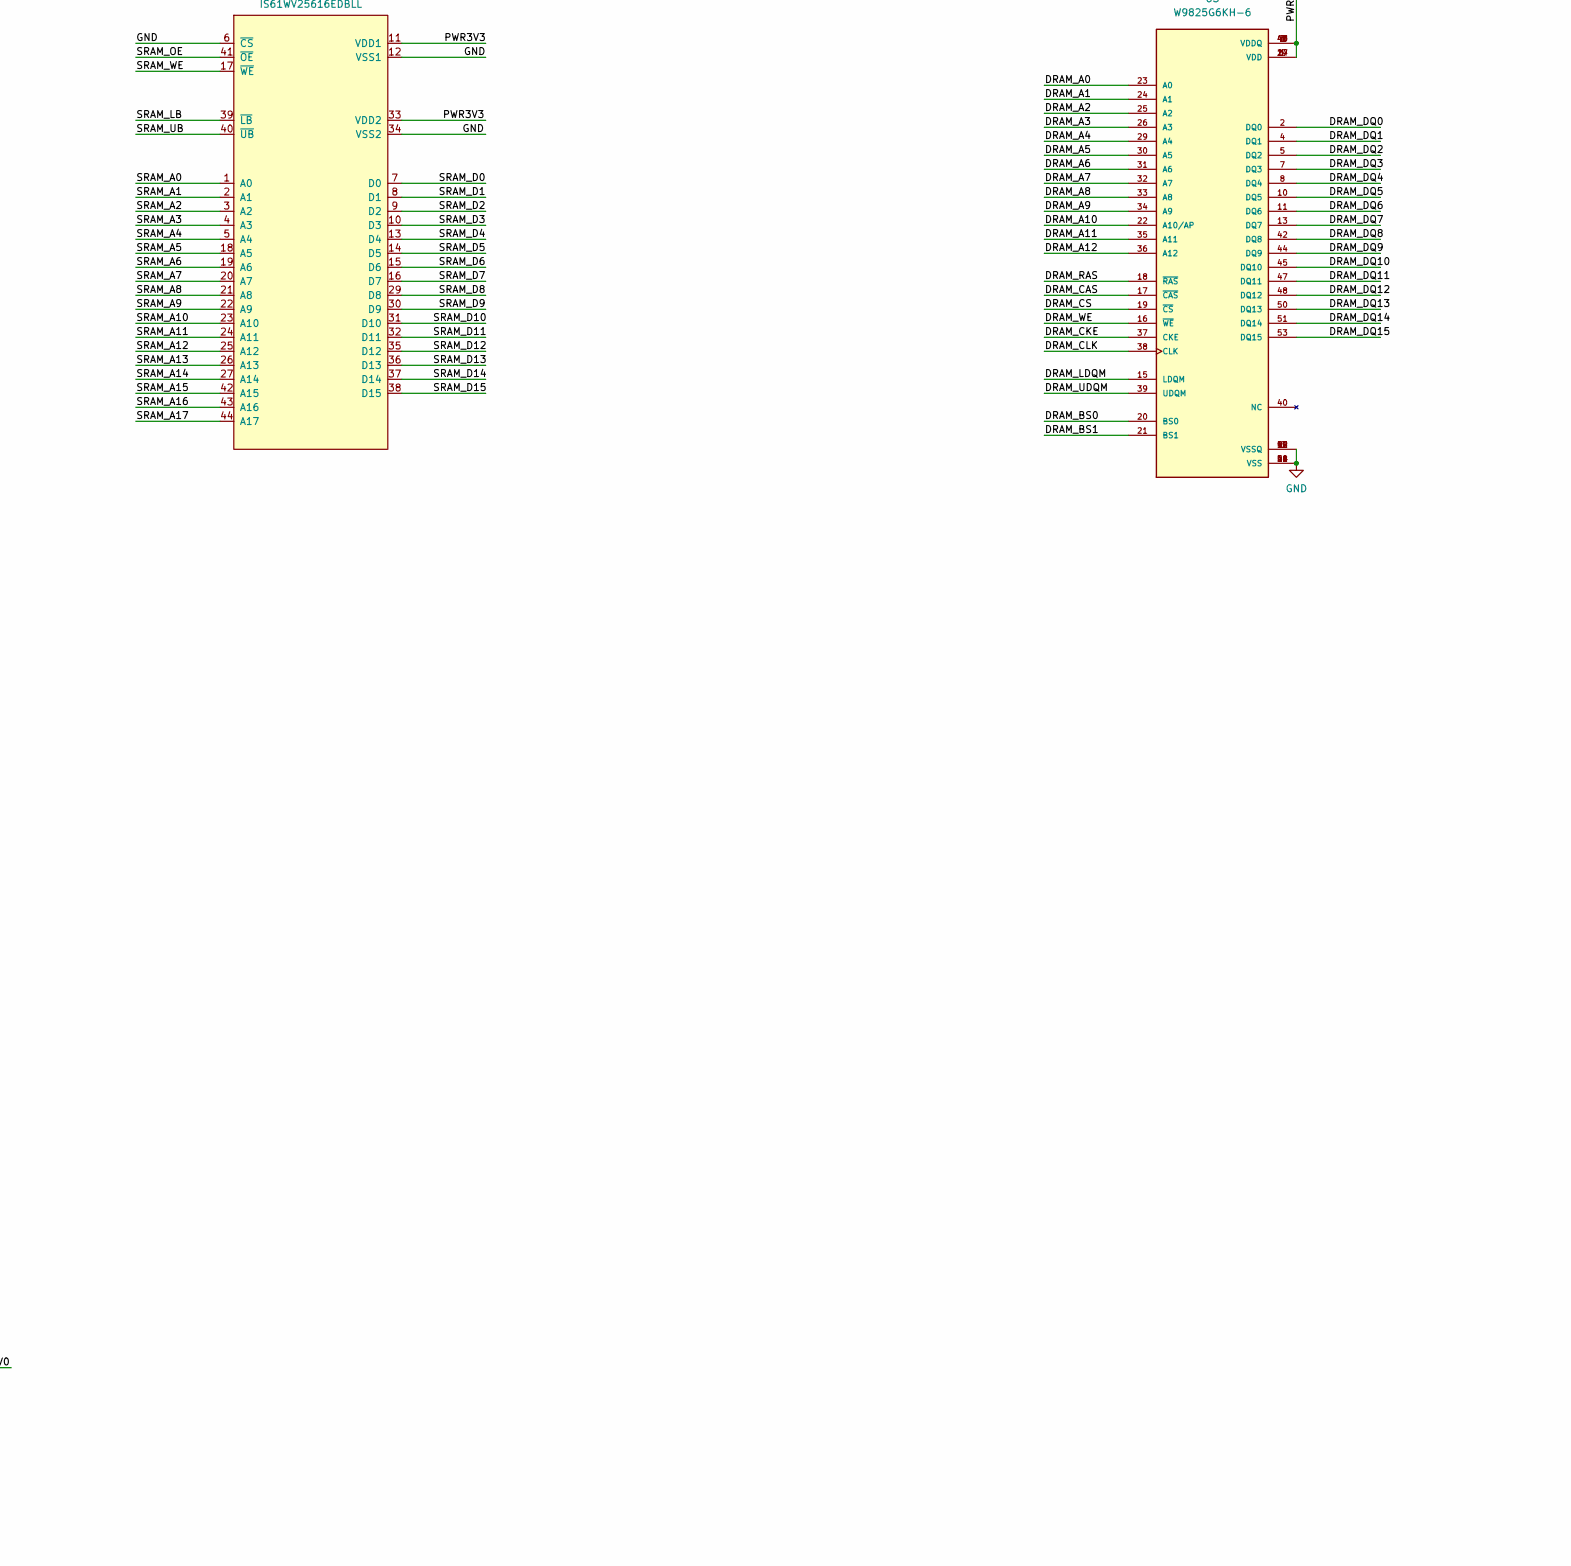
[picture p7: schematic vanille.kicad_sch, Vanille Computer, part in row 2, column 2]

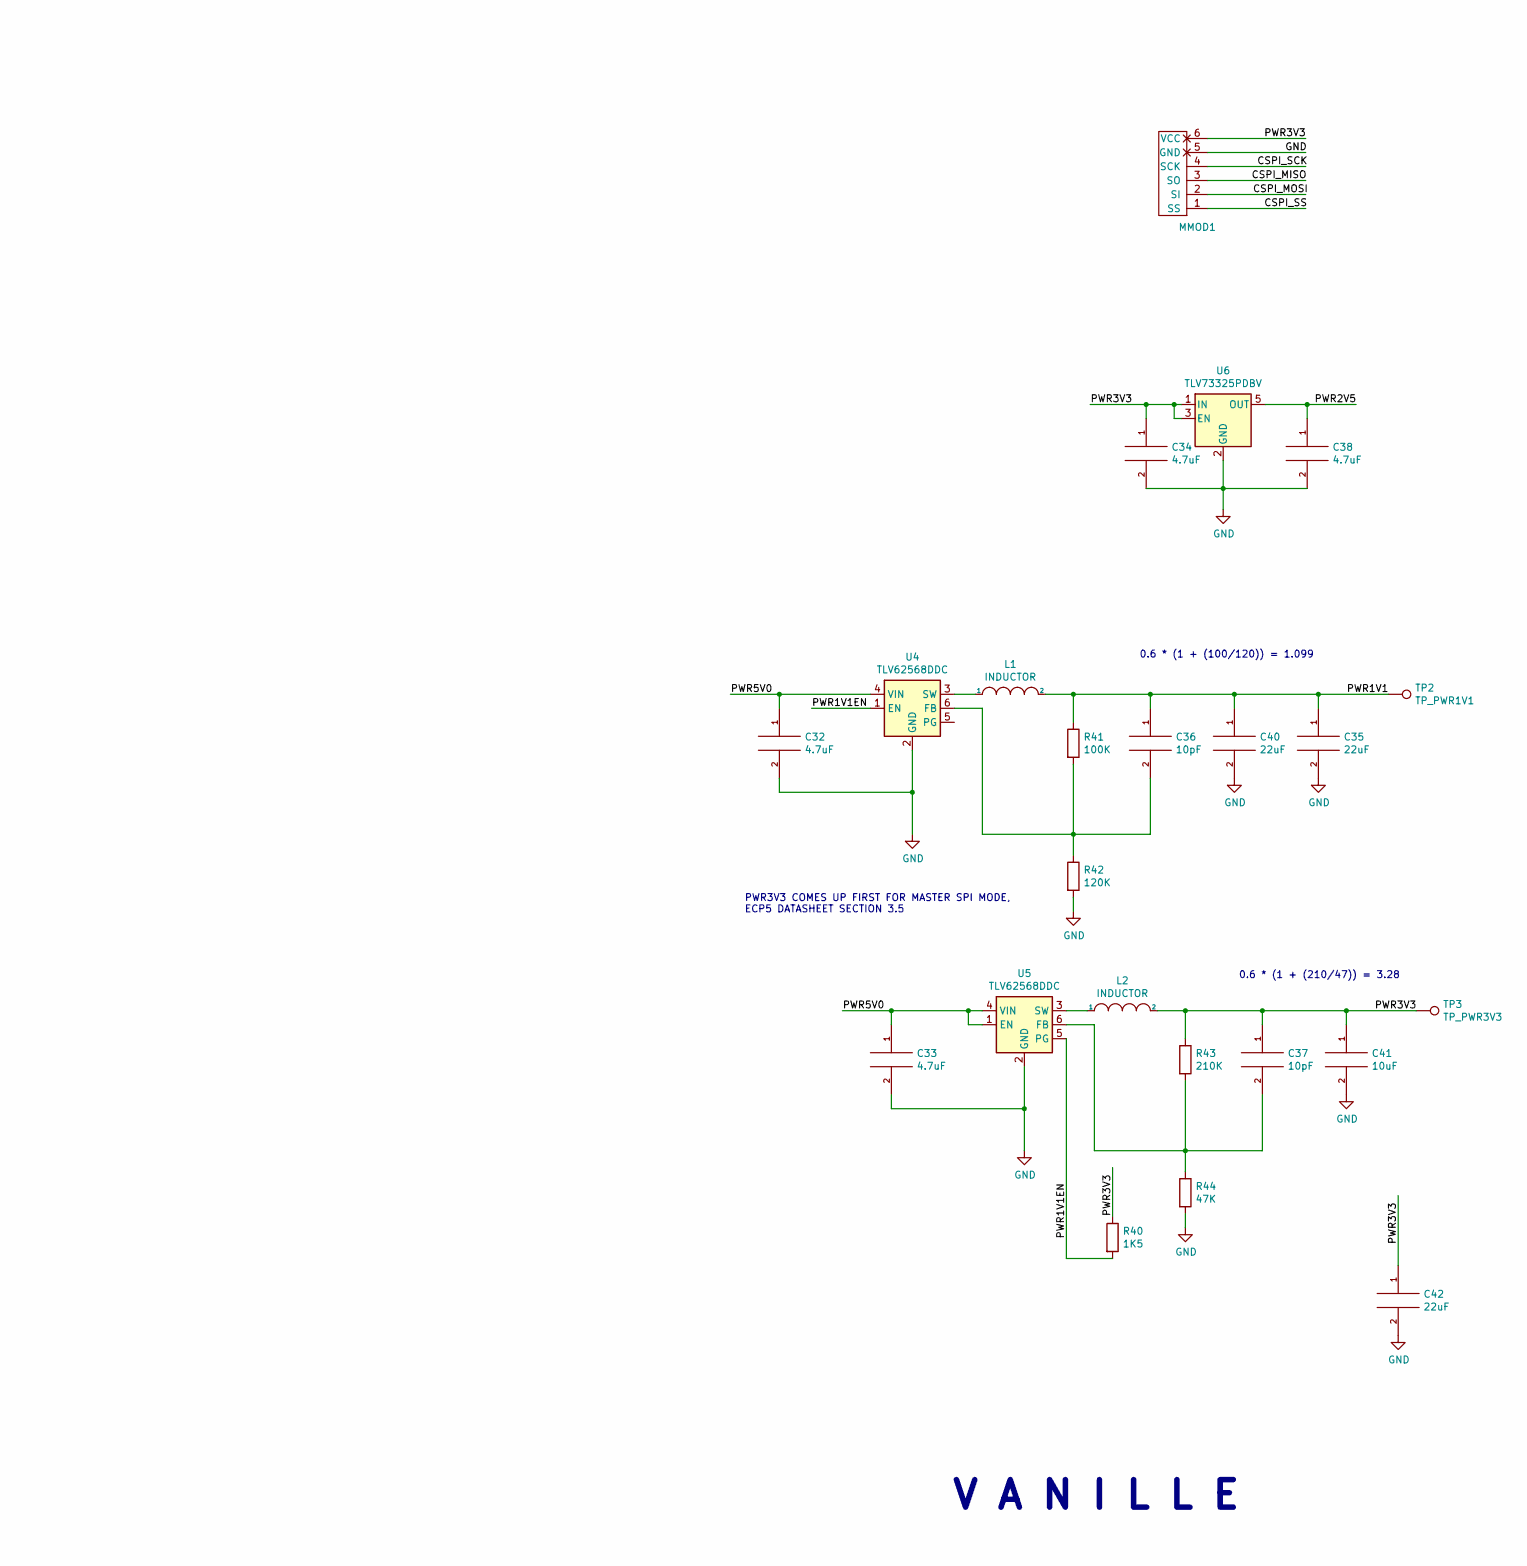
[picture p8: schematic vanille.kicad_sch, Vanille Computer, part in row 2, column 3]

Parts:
C1, C2, C3, C4, C5, C6, C7, C9, C10, C12, C13, C39, C43, C44, C45: 220nF; C_0603_1608Metric
C8, C11, C15, C19: 1uF; C_0603_1608Metric
C14, C16, C32, C33, C34, C38: 4.7uF; C_0603_1608Metric
C17, C20, C21, C22, C23, C24, C26, C27, C28: 100nF; C_0603_1608Metric
C18: 2.2uF; C_0603_1608Metric
C25, C29, C30, C41: 10uF; C_0603_1608Metric
C31: 100nF; R_0603_1608Metric
C35, C40, C42: 22uF; C_0603_1608Metric
C36, C37: 10pF; C_0603_1608Metric
D1: LEDW; LED_0603_1608Metric
FB1, FB2: Ferrite_Bead; R_0603_1608Metric
H1, H2, H3, H4: MountingHole_Pad; MountingHole_3.2mm_M3_Pad
J1: TYPE-C-31-M-12-FIXED; USB_C_Receptacle_HRO_TYPE-C-31-M-12-BIG-PADS; PARTREV A
J2: USB_A; USB_A_Stewart_SS-52100-001_Horizontal
J3: MICROSD; SDCARD
J5: DDMI_A; HDMI_TE_1827059-3-FIXED
JTAG1: Conn_02x03_Top_Bottom; PinHeader_2x03_P2.54mm_Vertical
L1, L2: INDUCTOR; L_0805_2012Metric
MMOD1: PMOD-Device-x1-Type-2-SPI; MMOD_Host_Socket
R1, R2: 4K7; R_0603_1608Metric
R3, R10: 5K1; R_0603_1608Metric
R5, R40: 1K5; R_0603_1608Metric
R6, R11: 1K; R_0603_1608Metric
R7, R8, R17, R18: 22R; R_0603_1608Metric
R9: 51R; R_0603_1608Metric
R19, R20: 15K; R_0603_1608Metric
R41: 100K; R_0603_1608Metric
R42: 120K; R_0603_1608Metric
R43: 210K; R_0603_1608Metric
R44: 47K; R_0603_1608Metric
RN1, RN2: 270R; R_Array_Convex_4x0402
RN3: 20K; R_Array_Convex_4x0402
RN4: 4K7; R_Array_Convex_4x0402
TP1: TP_PWR5V0; TestPoint_THTPad_D1.0mm_Drill0.5mm
TP2: TP_PWR1V1; TestPoint_THTPad_D1.0mm_Drill0.5mm
TP3: TP_PWR3V3; TestPoint_THTPad_D1.0mm_Drill0.5mm
U1: LFE5U-12-TG144
U2: IS61WV25616EDBLL; TSOP-II-44_10.16x18.41mm_P0.8mm
U3: W9825G6KH-6; SOP80P1176X120-54N; PARTREV A05
U4, U5: TLV62568DDC; SOT-23-6
U6: TLV73325PDBV; SOT-23-5
Y1: KC2016Z48; OSC_KC2016Z13.5600C1KX00; PARTREV November 2020

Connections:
/CLK48: U1.128 (PT29A/+/PCLKT0_0), Y1.3 (OUTPUT)
/CSPI_MISO: J3.7 (DAT0), MMOD1.3 (SO), RN3.8 (R1.2), U1.46 (PB11A/+/D1/MISO/IO1)
/CSPI_MOSI: J3.3 (CMD), MMOD1.2 (SI), RN3.6 (R3.2), U1.47 (PB11B/-/D0/MOSI/IO0)
/CSPI_SCK: MMOD1.4 (SCK), R6.2, U1.54 (CCLK/MCLK/SCK)
/CSPI_SS: MMOD1.1 (SS), U1.49 (PB15A/+/HOLDN/DI/BUSY/CSSPIN/CEN)
/DONE: U1.56 (DONE)
/DRAM_A0: U1.81 (PR35A/+/HS/RDQ32), U3.23 (A0)
/DRAM_A1: U1.80 (PR35C/+/RDQ32), U3.24 (A1)
/DRAM_A2: U1.79 (PR35B/-/HS/RDQ32/VREF1_3), U3.25 (A2)
/DRAM_A3: U1.78 (PR35D/-/RDQ32), U3.26 (A3)
/DRAM_A4: U1.105 (PR8A/+/HS/RDQS8), U3.29 (A4)
/DRAM_A5: U1.106 (PR2D/-/RDQ8), U3.30 (A5)
/DRAM_A6: U1.107 (PR2C/+/RDQ8), U3.31 (A6)
/DRAM_A7: U1.108 (PR2B/-/HS/RDQ8/S0_IN), U3.32 (A7)
/DRAM_A8: U1.110 (PT67A/+), U3.33 (A8)
/DRAM_A9: U1.111 (PT62B/-), U3.34 (A9)
/DRAM_A10: U1.82 (PR32D/-/RDQ32), U3.22 (A10/AP)
/DRAM_A11: U1.112 (PT62A/+), U3.35 (A11)
/DRAM_A12: U1.113 (PT60B/-), U3.36 (A12)
/DRAM_BS0: U1.92 (PR20D/-/RDQ20), U3.20 (BS0)
/DRAM_BS1: U1.91 (PR23A/+/HS/RDQ20/PCLKT2_1), U3.21 (BS1)
/DRAM_CAS: U1.89 (PR23B/-/HS/RDQ20/PCLKC2_1), U3.17 (~CAS)
/DRAM_CKE: U1.114 (PT60A/+), U3.37 (CKE)
/DRAM_CLK: U1.72 (PR44C/+/RDQ44), U3.38 (CLK)
/DRAM_CS: U1.84 (PR32C/+/RDQ32), U3.19 (~CS)
/DRAM_DQ0: U1.104 (PR8C/+/RDQ8), U3.2 (DQ0)
/DRAM_DQ1: U1.103 (PR8B/-/HS/RDQSN8), U3.4 (DQ1)
/DRAM_DQ2: U1.102 (PR8D/-/RDQ8), U3.5 (DQ2)
/DRAM_DQ3: U1.99 (PR14A/+/HS/RDQ20), U3.7 (DQ3)
/DRAM_DQ4: U1.98 (PR14C/+/RDQ20/VREF1_2), U3.8 (DQ4)
/DRAM_DQ5: U1.97 (PR14B/-/HS/RDQ20), U3.10 (DQ5)
/DRAM_DQ6: U1.95 (PR20A/+/HS/RDQS20/GR_PCLK2_1), U3.11 (DQ6)
/DRAM_DQ7: U1.94 (PR20C/+/RDQ20/GR_PCLK2_0), U3.13 (DQ7)
/DRAM_DQ8: U1.116 (PT58A/+), U3.42 (DQ8)
/DRAM_DQ9: U1.117 (PT56B/-), U3.44 (DQ9)
/DRAM_DQ10: U1.118 (PT56A/+), U3.45 (DQ10)
/DRAM_DQ11: U1.119 (PT53B/-), U3.47 (DQ11)
/DRAM_DQ12: U1.120 (PT53A/+), U3.48 (DQ12)
/DRAM_DQ13: U1.121 (PT51A/+), U3.50 (DQ13)
/DRAM_DQ14: U1.124 (PT42B/-), U3.51 (DQ14)
/DRAM_DQ15: U1.125 (PT42A/+), U3.53 (DQ15)
/DRAM_LDQM: U1.93 (PR20B/-/HS/RDQSN20), U3.15 (LDQM)
/DRAM_RAS: U1.88 (PR23D/-/RDQ20/PCLKC2_0), U3.18 (~RAS)
/DRAM_UDQM: U1.115 (PT58B/-), U3.39 (UDQM)
/DRAM_WE: U1.90 (PR23C/+/RDQ20/PCLKT2_0), U3.16 (~WE)
/DVIC_CK_N: J5.12 (CK-), RN2.1 (R1.1)
/DVIC_CK_P: J5.10 (CK+), RN2.2 (R2.1)
/DVIC_D0_N: J5.9 (D0-), RN2.3 (R3.1)
/DVIC_D0_P: J5.7 (D0+), RN2.4 (R4.1)
/DVIC_D1_N: J5.6 (D1-), RN1.1 (R1.1)
/DVIC_D1_P: J5.4 (D1+), RN1.2 (R2.1)
/DVIC_D2_N: J5.3 (D2-), RN1.3 (R3.1)
/DVIC_D2_P: J5.1 (D2+), RN1.4 (R4.1)
/DVI_CK_N: RN2.8 (R1.2), U1.68 (PR47D/-/RDQ44/LRC_GPLL0C_IN)
/DVI_CK_P: RN2.7 (R2.2), U1.69 (PR47C/+/RDQ44/LRC_GPLL0T_IN)
/DVI_D0_N: RN2.6 (R3.2), U1.67 (PR47B/-/HS/RDQ44)
/DVI_D0_P: RN2.5 (R4.2), U1.71 (PR47A/+/HS/RDQ44)
/DVI_D1_N: RN1.8 (R1.2), U1.73 (PR41D/-/RDQ44)
/DVI_D1_P: RN1.7 (R2.2), U1.74 (PR41C/+/RDQ44)
/DVI_D2_N: RN1.6 (R3.2), U1.76 (PR41B/-/HS/RDQ44)
/DVI_D2_P: RN1.5 (R4.2), U1.77 (PR41A/+/HS/RDQ44)
/INITN: R1.2, U1.55 (INITN)
/JTAG_TCK: JTAG1.1, RN4.8 (R1.2), U1.63 (TCK)
/JTAG_TDI: JTAG1.2, RN4.6 (R3.2), U1.61 (TDI)
/JTAG_TDO: JTAG1.3, RN4.5 (R4.2), U1.60 (TDO)
/JTAG_TMS: JTAG1.4, RN4.7 (R2.2), U1.64 (TMS)
/LED: D1.1 (K), U1.52 (PB18A/WRITEN)
/PROGRAMN: R2.2, R9.2, U1.57 (PROGRAMN)
/PWR1V1: C3.2, C5.2, C10.2, C12.2, C13.2, C15.2, C19.2, C35.1, C36.1, C39.2, C40.1, L1.2, R41.1, TP2.1, U1.20 (VCC[6]), U1.29 (VCC[6]), U1.38 (VCC[6]), U1.66 (VCC[6]), U1.83 (VCC[6]), U1.130 (VCC[6])
/PWR1V1EN: R40.2, U4.1 (EN), U5.5 (PG)
/PWR2V5: C4.2, C38.1, U1.17 (VCCAUX[4]), U1.53 (VCCAUX[4]), U1.96 (VCCAUX[4]), U1.132 (VCCAUX[4]), U6.5 (OUT)
/PWR3V3: C1.2, C2.2, C6.2, C7.2, C8.2, C9.2, C11.2, C17.2, C18.2, C20.2, C21.2, C22.2, C23.2, C24.2, C25.1, C26.2, C27.1, C28.2, C29.2, C30.2, C31.1, C34.1, C37.1, C41.1, C42.1, C43.2, C44.2, C45.2, J3.4 (VDD), L2.2, MMOD1.6 (VCC), R1.1, R2.1, R6.1, R11.1, R40.1, R43.1, RN3.1 (R1.1), RN3.2 (R2.1), RN3.3 (R3.1), RN3.4 (R4.1), RN4.2 (R2.1), RN4.3 (R3.1), RN4.4 (R4.1), TP3.1, U1.9 (VCCIO7), U1.16 (VCCIO6[2]), U1.36 (VCCIO6[2]), U1.43 (VCCIO8), U1.59 (CFG_1), U1.70 (VCCIO3[2]), U1.86 (VCCIO3[2]), U1.100 (VCCIO2), U1.122 (VCCIO1), U1.137 (VCCIO0), U2.11 (VDD1), U2.33 (VDD2), U3.1 (VDD), U3.3 (VDDQ), U3.9 (VDDQ), U3.14 (VDD), U3.27 (VDD), U3.43 (VDDQ), U3.49 (VDDQ), U6.1 (IN), U6.3 (EN), Y1.1 (INH), Y1.4 (VCC)
/PWR5V0: C14.1, C32.1, C33.1, FB1.1, FB2.1, J5.18 (+5V), JTAG1.5, TP1.1, U4.4 (VIN), U5.1 (EN), U5.4 (VIN)
/PWR5V0UF: FB1.2, J1.A4 (VBUS), J1.A9 (VBUS), J1.B4 (VBUS), J1.B9 (VBUS)
/RESET: R9.1, U1.51 (PB15B/-/DOUT/CSON)
/SD_SCK: J3.5 (CLK), RN3.7 (R2.2), U1.50 (PB13B/-/CS1N)
/SD_SS: J3.2 (DAT3/CD), RN3.5 (R4.2), U1.48 (PB13A/+/SN/CSN)
/SRAM_A0: U1.133 (PT15B/-), U2.1 (A0)
/SRAM_A1: U1.134 (PT15A/+), U2.2 (A1)
/SRAM_A2: U1.135 (PT13B/-), U2.3 (A2)
/SRAM_A3: U1.136 (PT13A/+), U2.4 (A3)
/SRAM_A4: U1.127 (PT40A/+), U2.5 (A4)
/SRAM_A5: U1.4 (PL8A/+/HS/LDQS8), U2.18 (A5)
/SRAM_A6: U1.5 (PL8C/+/LDQ8), U2.19 (A6)
/SRAM_A7: U1.14 (PL23D/-/LDQ20/PCLKC7_0), U2.20 (A7)
/SRAM_A8: U1.28 (PL44A/+/HS/LDQS44), U2.21 (A8)
/SRAM_A9: U1.37 (PL47C/+/LDQ44/LLC_GPLL0T_IN), U2.22 (A9)
/SRAM_A10: U1.35 (PL47B/-/HS/LDQ44), U2.23 (A10)
/SRAM_A11: U1.34 (PL47A/+/HS/LDQ44), U2.24 (A11)
/SRAM_A12: U1.33 (PL44D/-/LDQ44), U2.25 (A12)
/SRAM_A13: U1.31 (PL44C/+/LDQ44), U2.26 (A13)
/SRAM_A14: U1.30 (PL44B/-/HS/LDQSN44), U2.27 (A14)
/SRAM_A15: U1.10 (PL14A/+/HS/LDQ20), U2.42 (A15)
/SRAM_A16: U1.7 (PL8D/-/LDQ8), U2.43 (A16)
/SRAM_A17: U1.6 (PL8B/-/HS/LDQSN8), U2.44 (A17)
/SRAM_D0: U1.139 (PT9B/-), U2.7 (D0)
/SRAM_D1: U1.140 (PT9A/+), U2.8 (D1)
/SRAM_D2: U1.141 (PT6B/-), U2.9 (D2)
/SRAM_D3: U1.142 (PT4B/-), U2.10 (D3)
/SRAM_D4: U1.143 (PT6A/+), U2.13 (D4)
/SRAM_D5: U1.1 (PL5C/+/LDQ8), U2.14 (D5)
/SRAM_D6: U1.3 (PL5B/-/HS/LDQ8), U2.15 (D6)
/SRAM_D7: U1.2 (PL5D/-/LDQ8), U2.16 (D7)
/SRAM_D8: U1.27 (PL41D/-/LDQ44), U2.29 (D8)
/SRAM_D9: U1.26 (PL41C/+/LDQ44), U2.30 (D9)
/SRAM_D10: U1.25 (PL38B/-/HS/LDQ44), U2.31 (D10)
/SRAM_D11: U1.24 (PL38A/+/HS/LDQ44), U2.32 (D11)
/SRAM_D12: U1.23 (PL35D/-/LDQ32), U2.35 (D12)
/SRAM_D13: U1.22 (PL35C/+/LDQ32), U2.36 (D13)
/SRAM_D14: U1.19 (PL35B/-/HS/LDQ32/VREF1_6), U2.37 (D14)
/SRAM_D15: U1.18 (PL32B/-/HS/LDQSN32), U2.38 (D15)
/SRAM_LB: U1.13 (PL14D/-/LDQ20), U2.39 (~LB)
/SRAM_OE: U1.11 (PL14C/+/LDQ20/VREF1_7), U2.41 (~OE)
/SRAM_UB: U1.12 (PL14B/-/HS/LDQ20), U2.40 (~UB)
/SRAM_WE: U1.126 (PT40B/-), U2.17 (~WE)
/USB0_CONN_DN: J1.A7 (DN1), J1.B7 (DN2), R8.1
/USB0_CONN_DP: J1.A6 (DP1), J1.B6 (DP2), R5.2, R7.1
/USB0_DN: R8.2, U1.44 (PB4B/-/D6/IO6)
/USB0_DP: R7.2, U1.40 (PB4A/+/D7/IO7)
/USB0_DP_PU: R5.1, U1.45 (PB9A/+/D3/IO3)
/USB1_CONN_DN: J2.2 (D-), R18.1, R20.1
/USB1_CONN_DP: J2.3 (D+), R17.1, R19.1
/USB1_DN: R18.2, U1.41 (PB6B/-/D4/MOSI2/IO4)
/USB1_DP: R17.2, U1.39 (PB6A/+/D5/MISO2/IO5)
GND: C1.1, C2.1, C3.1, C4.1, C5.1, C6.1, C7.1, C8.1, C9.1, C10.1, C11.1, C12.1, C13.1, C14.2, C15.1, C16.2, C17.1, C18.1, C19.1, C20.1, C21.1, C22.1, C23.1, C24.1, C25.2, C26.1, C27.2, C28.1, C29.1, C30.1, C31.2, C32.2, C33.2, C34.2, C35.2, C38.2, C39.1, C40.2, C41.2, C42.2, C43.1, C44.1, C45.1, H1.1, H2.1, H3.1, H4.1, J1.A1 (GND), J1.A12 (GND), J1.B1 (GND), J1.B12 (GND), J1.S1 (SHIELD), J1.S2 (SHIELD), J1.S3 (SHIELD), J1.S4 (SHIELD), J2.4 (GND), J2.5 (Shield), J3.6 (VSS), J5.2 (D2S), J5.5 (D1S), J5.8 (D0S), J5.11 (CKS), J5.17 (GND), J5.S1 (SH), J5.S2 (SH), J5.S3 (SH), J5.S4 (SH), JTAG1.6, MMOD1.5 (GND), R3.2, R10.2, R19.2, R20.2, R42.2, R44.2, RN4.1 (R1.1), U1.8 (GND[13]), U1.15 (GND[13]), U1.21 (GND[13]), U1.32 (VSSIO6), U1.42 (GND[13]), U1.58 (CFG_2), U1.62 (CFG_0), U1.65 (GND[13]), U1.75 (GND[13]), U1.85 (GND[13]), U1.87 (GND[13]), U1.101 (GND[13]), U1.123 (GND[13]), U1.129 (GND[13]), U1.131 (GND[13]), U1.138 (GND[13]), U2.6 (~CS), U2.12 (VSS1), U2.34 (VSS2), U3.6 (VSSQ), U3.12 (VSSQ), U3.28 (VSS), U3.41 (VSS), U3.46 (VSSQ), U3.52 (VSSQ), U3.54 (VSS), U4.2 (GND), U5.2 (GND), U6.2 (GND), Y1.2 (CASE_GND)
unnamed: D1.2 (A), R11.2
unnamed: J1.A5 (CC1), R3.1
unnamed: J1.B5 (CC2), R10.1
unnamed: C16.1, FB2.2, J2.1 (VBUS)
unnamed: C36.2, R41.2, R42.1, U4.6 (FB)
unnamed: L1.1, U4.3 (SW)
unnamed: C37.2, R43.2, R44.1, U5.6 (FB)
unnamed: L2.1, U5.3 (SW)

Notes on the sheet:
V A N I L L E
PWR3V3 COMES UP FIRST FOR MASTER SPI MODE, ECP5 DATASHEET SECTION 3.5
0.6 * (1 + (210/47)) = 3.28
MMOD has a 10K pull-up on CSPI_SS
0.6 * (1 + (100/120)) = 1.099

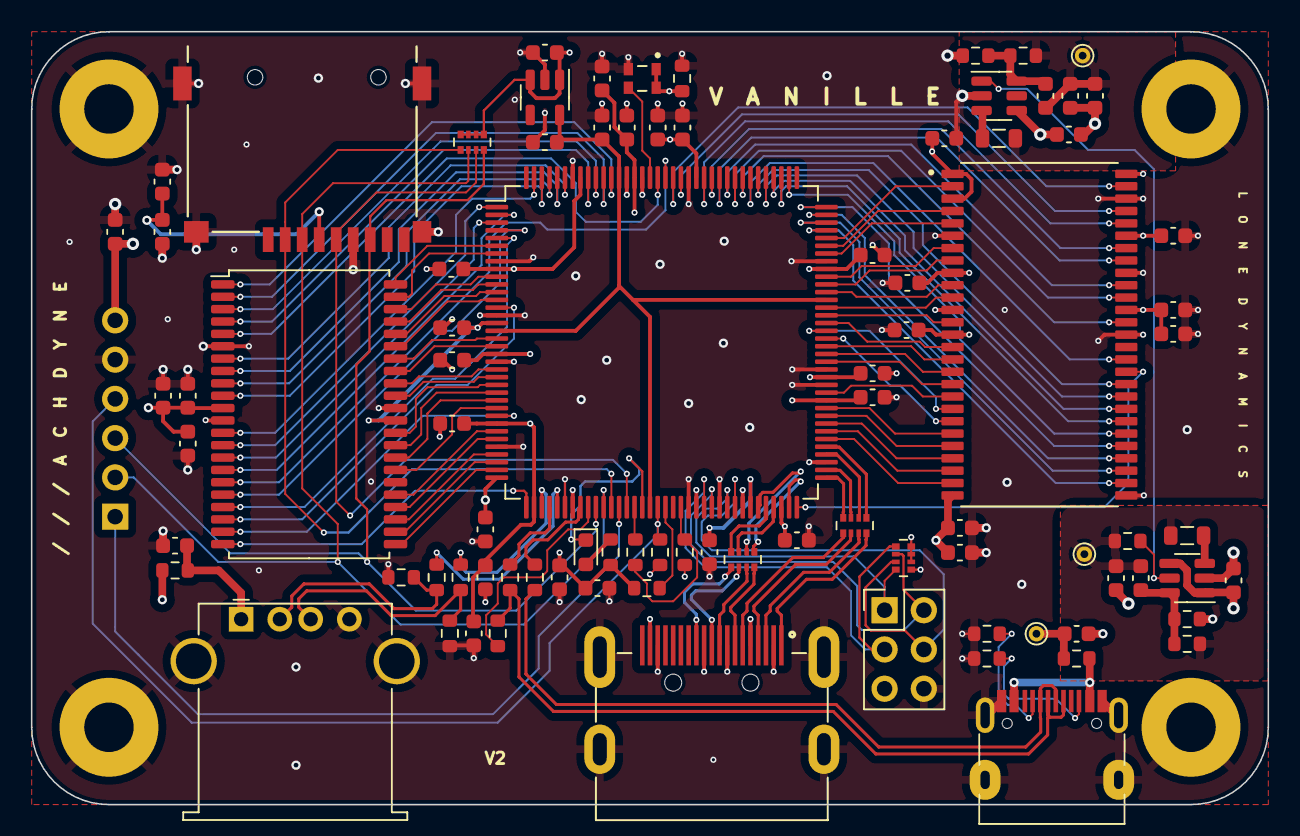
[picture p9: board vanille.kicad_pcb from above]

Board: 4 copper layers, 80.0 x 50.0 mm, 93 parts (1 on the bottom side), 132 nets.

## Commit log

2024-02-11 add fpga symbol/scripts
    [FPGA-SC-02032-2-0-ECP5U-12-Pinout.csv, pinout.csv]
2024-02-11 add v0 pcb
    [vanille.kicad_pcb, vanille.kicad_sch]
2024-02-21 add v1 pcb
    [vanille.kicad_pcb, vanille.kicad_sch]
2024-02-25 add v1 schematic pdf
2024-02-29 add v2
    [mdc.kicad_pcb, mdc.kicad_sch]
2024-02-29 rename files
    [vanille.kicad_pcb, vanille.kicad_sch]
2024-03-13 latest schematics pdf

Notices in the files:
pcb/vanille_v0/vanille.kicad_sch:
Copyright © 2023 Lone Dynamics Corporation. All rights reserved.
